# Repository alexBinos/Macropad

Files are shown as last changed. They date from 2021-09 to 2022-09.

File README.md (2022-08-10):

# Macropad

A 20 key macro-keyboard with extra hardware features including;

- 1x rotary encoder
- I2C breakout to support an OLED display
- Per-key RGB LED lighting and underglow lighting
- Hot-swap key switch sockets
- 4 port USB 2.0 HUB with 3 spare downstream ports

<br>

Power for the board and downstream USB ports is sourced from the upstream USB port. The board consumes 62mA with all LEDs powered off giving 438mA to be shared among the remaining 3 USB ports. With all LEDs powered up to pixel value 128 (recommended maximum) the board consumes 264mA.

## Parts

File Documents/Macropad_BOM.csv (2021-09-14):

Id | Designator | Package | Quantity | Designation | Description
1 | SW22 | SW_SPST_B3U-1000P | 1 | SW_Push | DFU reset switch
2 | D54;D53;D52;D51;D50;D49;D48;D47;D46;D45;D44;D43;D42;D41;D40;D39;D38;D37;D36;D35;D34;D33;D32;D31;D30;D28;D27;D26;D25;D24; | SK6812-MINI-E | 30 |  | RGB LEDs
3 | TP2;TP3;TP1 | TestPoint_Pad_D1.0mm | 3 | TestPoint | Test points (DNP)
4 | C30;C39;C46;C45;C37;C44;C2;C36;C33 | C_0603_1608Metric | 9 | 1uF | 0603 capacitor
5 | C16;C20;C14;C23;C38;C43;C42;C41;C40;C3;C35;C34;C32;C31;C29;C28;C27;C26;C25;C24;C22;C21;C19;C18;C17;C15;C13;C12;C11;C10;C9;C8;C7;C6;C5;C4 | C_0603_1608Metric | 36 | 100nF | 0603 capacitor
6 | U8;U6;U2 | SOT-23-6 | 3 | SRV05-4 | ESD diode array
7 | J5;J6;J4;J1 | USB_C_Receptacle_GCT_USB4085 | 4 | USB_C_Receptacle_USB2.0 | USB C connector
8 | FB3;FB2;FB1 | L_0805_2012Metric | 3 | Ferrite_Bead | Ferrite bead
9 | SW12;SW7;SW17;SW2;SW16;SW18;SW8;SW11;SW6;SW13;SW3;SW1;SW20;SW19;SW15;SW14;SW10;SW9;SW5;SW4; | CherryMX_1.00u_PCB_KailhSocket | 20 |  | Hot swap switch receptacle
10 | J3 | PinHeader_2x03_P2.54mm_Vertical_SMD | 1 | Conn_02x03_Odd_Even | ISP header
11 | U4 | TUSB2046b | 1 | TUSB2046b | USB hub controller
12 | R1;R13;R11;R10;R9;R21;R20;R19;R18;R14 | R_0603_1608Metric | 10 | 4K7 | 0603 resistor
13 | U5 | TQFP-44_10x10mm_P0.8mm | 1 | ATmega32U4-AU | uController
14 | X2 | 625L3C006M00000 | 1 | 625L3C006M00000 | 6MHz crystal (USB hub)
15 | R29;R28;R27;R26;R25;R24;R23;R22;R8;R7 | R_0603_1608Metric | 10 | 22R | 0603 resistor
16 | R6;R5 | R_0603_1608Metric | 2 | OPT | 0603 resistor
17 | R4;R3 | R_0603_1608Metric | 2 | 5K1 | 0603 resistor
18 | R2 | R_0603_1608Metric | 1 | 330R | 0603 resistor
19 | L1 | SMM2012E | 1 | L_Core_Iron_Coupled_1423 | Common mode choke
20 | D1 | D_0603_1608Metric | 1 | LED | Blue LED
21 | C1 | C_0603_1608Metric | 1 | 10uF | 0603 capacitor
22 | D22;D21;D20;D19;D18;D17;D16;D15;D14;D13;D12;D11;D10;D9;D8;D7;D6;D5;D4;D3;D2 | SOD323_HS | 21 | D | Diode
23 | X1 | KC2016K | 1 | KC2016K | 16MHz crystal (uController)
24 | U1 | TCR2EF33_SOT25 | 1 | TCR2EF33 | 3.3V 200mA LDO
25 | SW21 | RotaryEncoder_Alps_EC11E-Switch_Vertical_H20mm | 1 | Rotary_Encoder_Switch | Rotary encoder
26 | R16;R15 | R_0603_1608Metric | 2 | Rt | 0603 resistor
27 | J2 | PinSocket_1x04_P2.54mm_Vertical | 1 | Conn_01x04_Female | OLED display connector

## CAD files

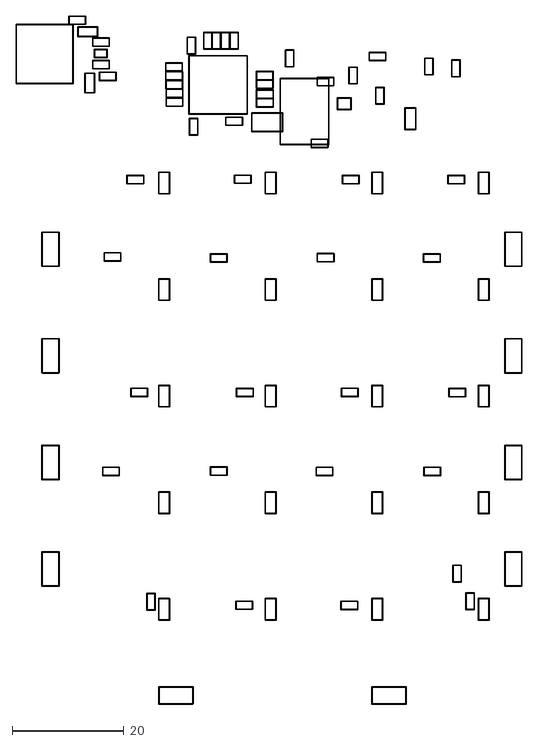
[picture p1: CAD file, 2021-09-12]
Mechanical/dxf/Macropad-B_CrtYd.dxf
90.4 x 123.0

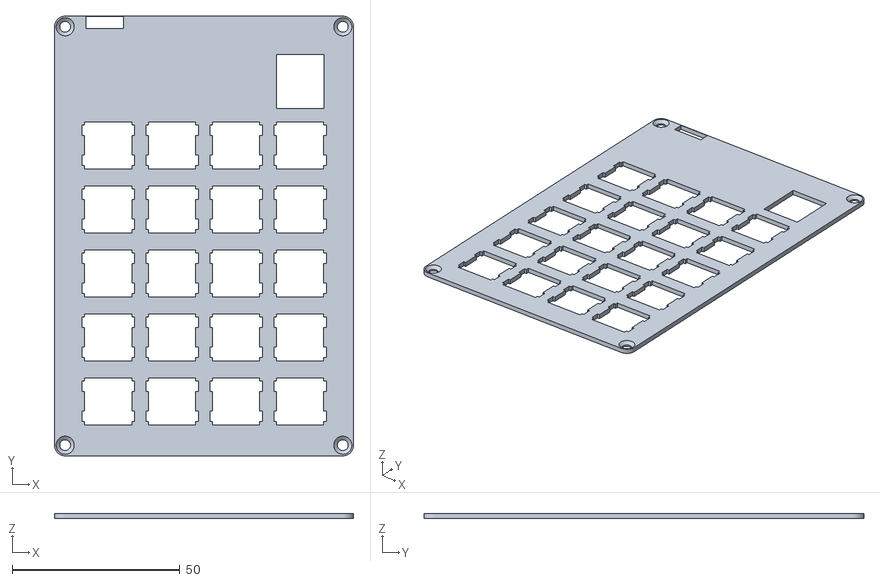
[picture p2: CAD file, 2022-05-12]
Mechanical/key_frame.STL
89.0 x 130.9 x 1.60

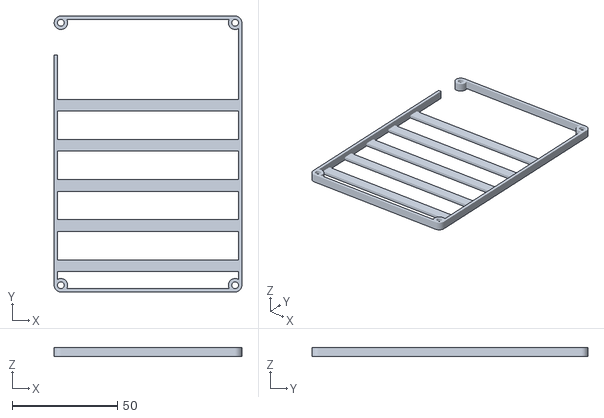
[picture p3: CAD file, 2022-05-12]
Mechanical/bottom_space_frame.STL
89.1 x 131.0 x 4.40

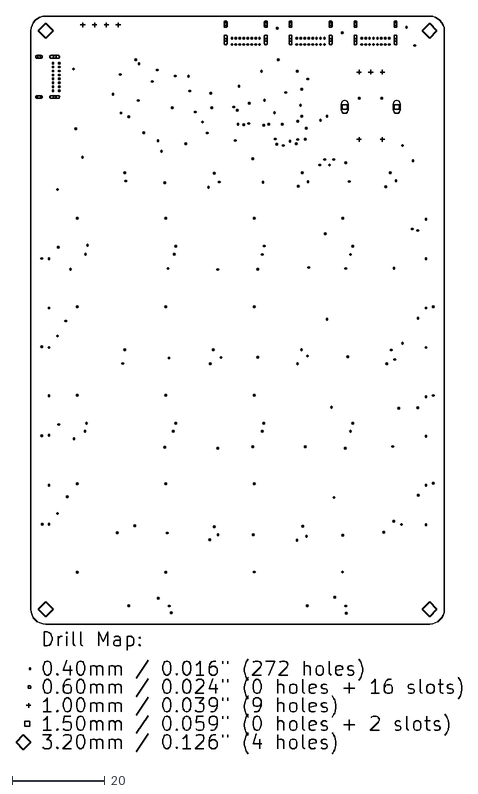
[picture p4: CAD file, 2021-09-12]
Mechanical/dxf/Macropad-PTH-drl_map.dxf
96.1 x 158.9

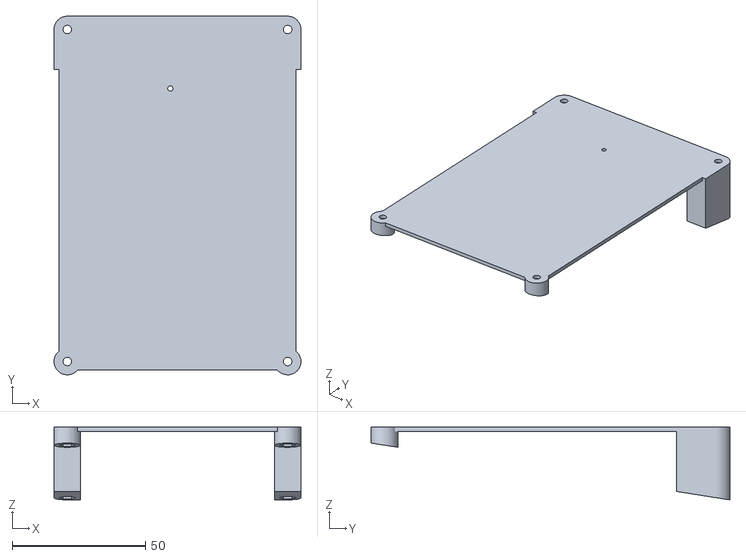
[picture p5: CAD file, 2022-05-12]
Mechanical/back_frame.STL
92.7 x 134.6 x 27.3

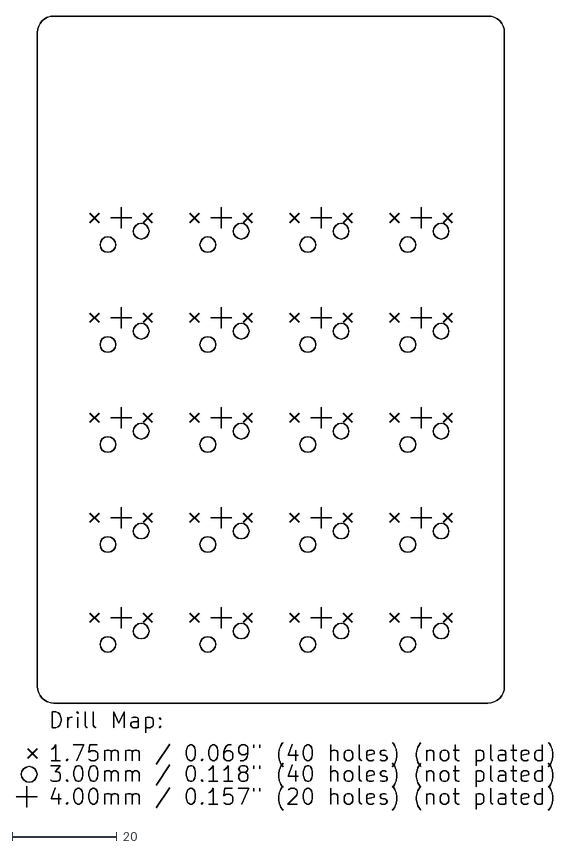
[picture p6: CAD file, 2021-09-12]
Mechanical/dxf/Macropad-NPTH-drl_map.dxf
102.3 x 151.3

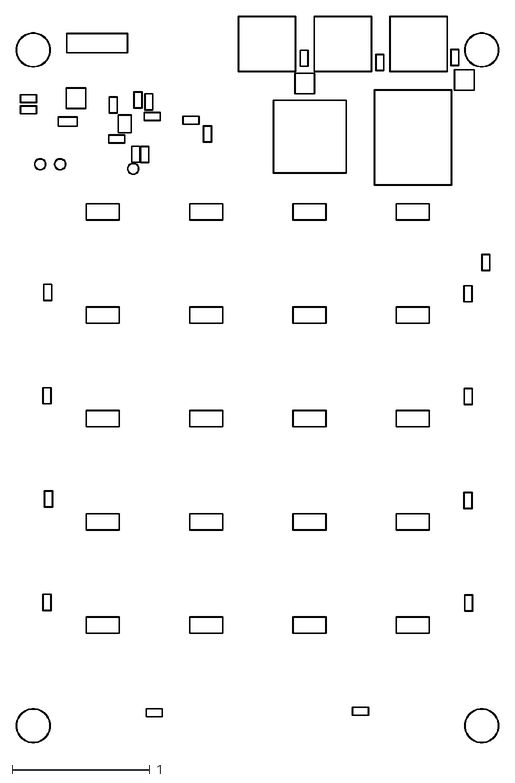
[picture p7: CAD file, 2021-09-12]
Mechanical/dxf/Macropad-F_CrtYd.dxf
3.50 x 5.27

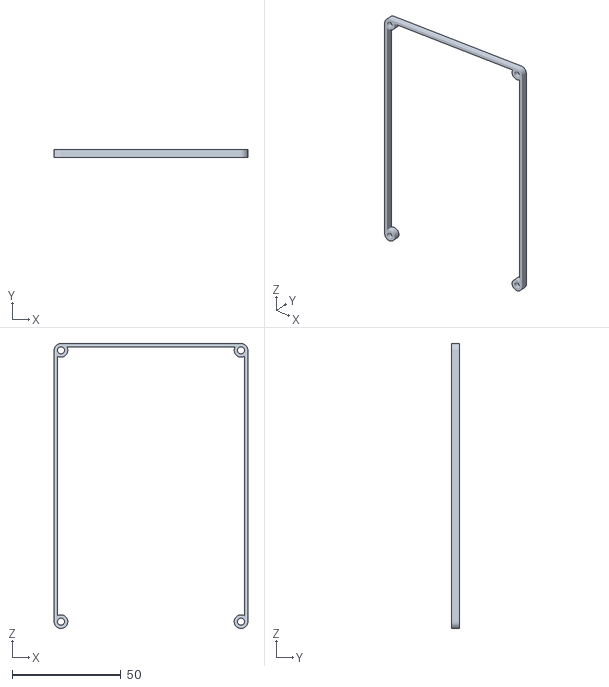
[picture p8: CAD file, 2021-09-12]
Mechanical/top_space_frame.STL
89.0 x 3.80 x 130.9

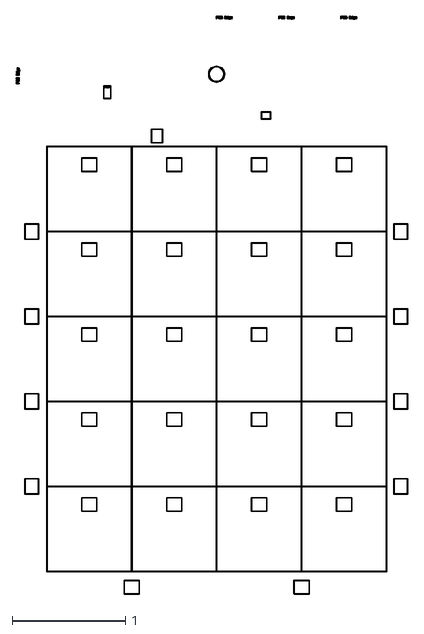
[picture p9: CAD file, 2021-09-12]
Mechanical/dxf/Macropad-Dwgs_User.dxf
3.45 x 5.10

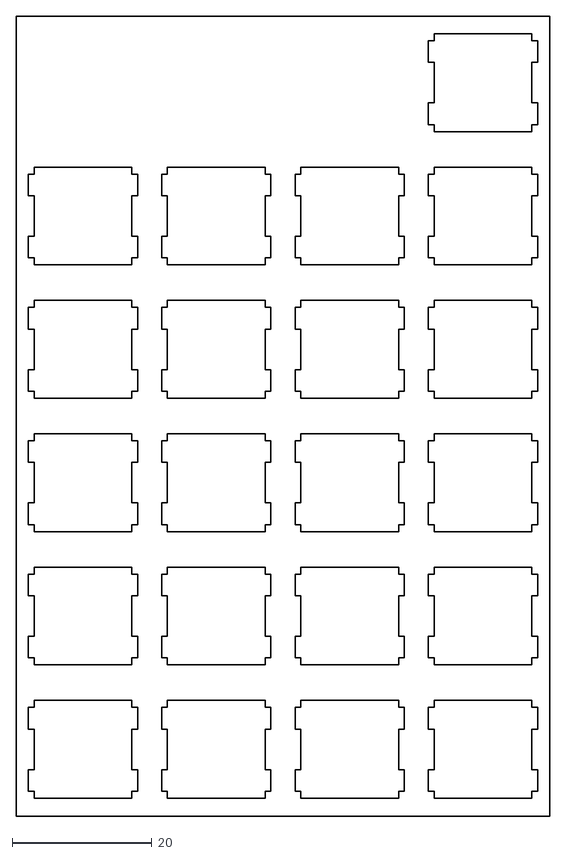
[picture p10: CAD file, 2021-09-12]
Mechanical/dxf/mx_key_frame_swillkb.dxf
76.2 x 114.3

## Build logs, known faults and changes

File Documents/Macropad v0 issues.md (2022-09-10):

## Macropad v0 issues

<br>

1. I2C lines connected incorrectly to ATMEGA32U4

The I2C lines are not connected to the dedicated I2C hardware pins PD1 and PD0 on the ATMEGA32U4. The OLED display cannot be driven on the v0 board.

*Fixes:* Cannot be fixed in hardware as the dedicated I2C pins are used to drive the switch matrix.

2. USB configuration resistors not connected correctly

Pull up/down resistors are required to be placed on the USB data lines to set the port directions on startup. Some USB HUB chips include these resistors in the package to simplify hardware design however the TUSB2046 does not include these and they need to be placed externally. AN-5052 provides a guide on how to correctly configure the USB data lines for host/peripheral configurations.

*Fixes:* 
<br>
To use the USB HUB, the 1K5 resistor can be soldered between R1 and R8. The 15K pull down resistors can be soldered between USB data lines and ground at the downstream connectors.
<br>
 
<p align="center" width="100%">
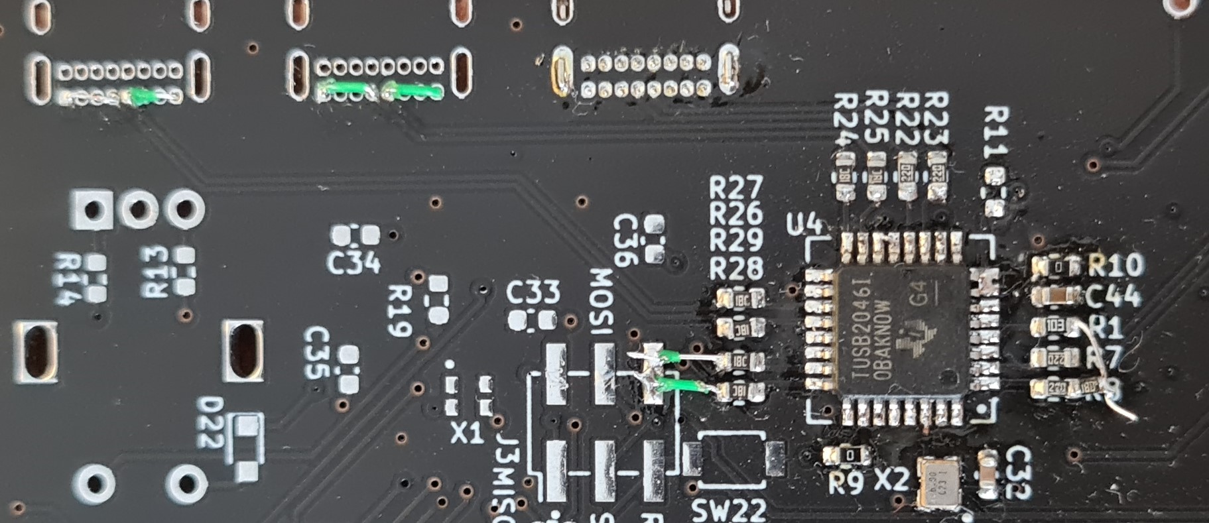
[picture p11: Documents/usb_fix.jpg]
     
</p>

<br>
If the USB HUB is not required, the TUSB2046 can not be placed and the USB data lines can be connected directly to the ATMEGA32U4 by joining pins 1 and 24, and pins 2 and 23 on the TUSB2046 footprint with wire.
<br>

<p align="center" width="100%">
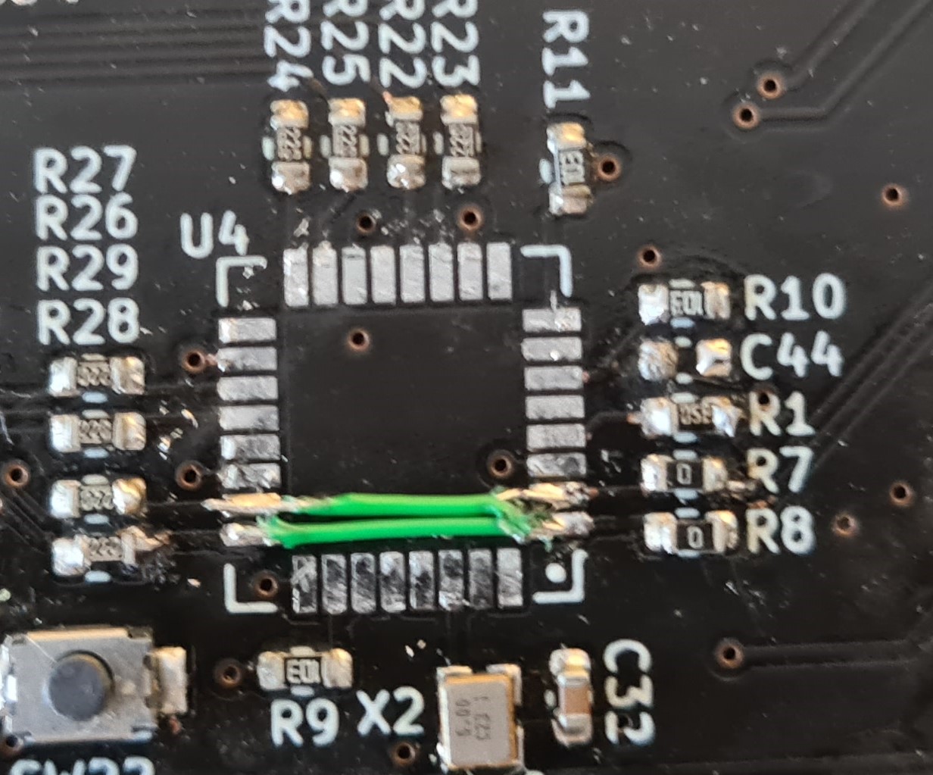
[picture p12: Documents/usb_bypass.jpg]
     
</p>

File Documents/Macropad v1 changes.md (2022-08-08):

## Macropad v1 changes

<br>

   1. Moved I2C lines to PD1/SDA and PD0/SCL
   2. Added 15K USB pull downs on USB HUB peripheral side
   3. Added 1K5 pull up on D+ on USB HUB host side
   4. Removed USB CMC bypass optionals
   5. Removed USB HUB configuration strap resistors
   6. Changed USB HUB BUSPWR mode to self powered (pulled down)
   7. Added optional pads to bypass the USB HUB
   8. Updated SK6812 footprint for better fitment
   9. Updated board name silk
   10. Moved underglow LED decoupling caps to avoid clashes with case
   11. Rounded corners on +3V3 plane

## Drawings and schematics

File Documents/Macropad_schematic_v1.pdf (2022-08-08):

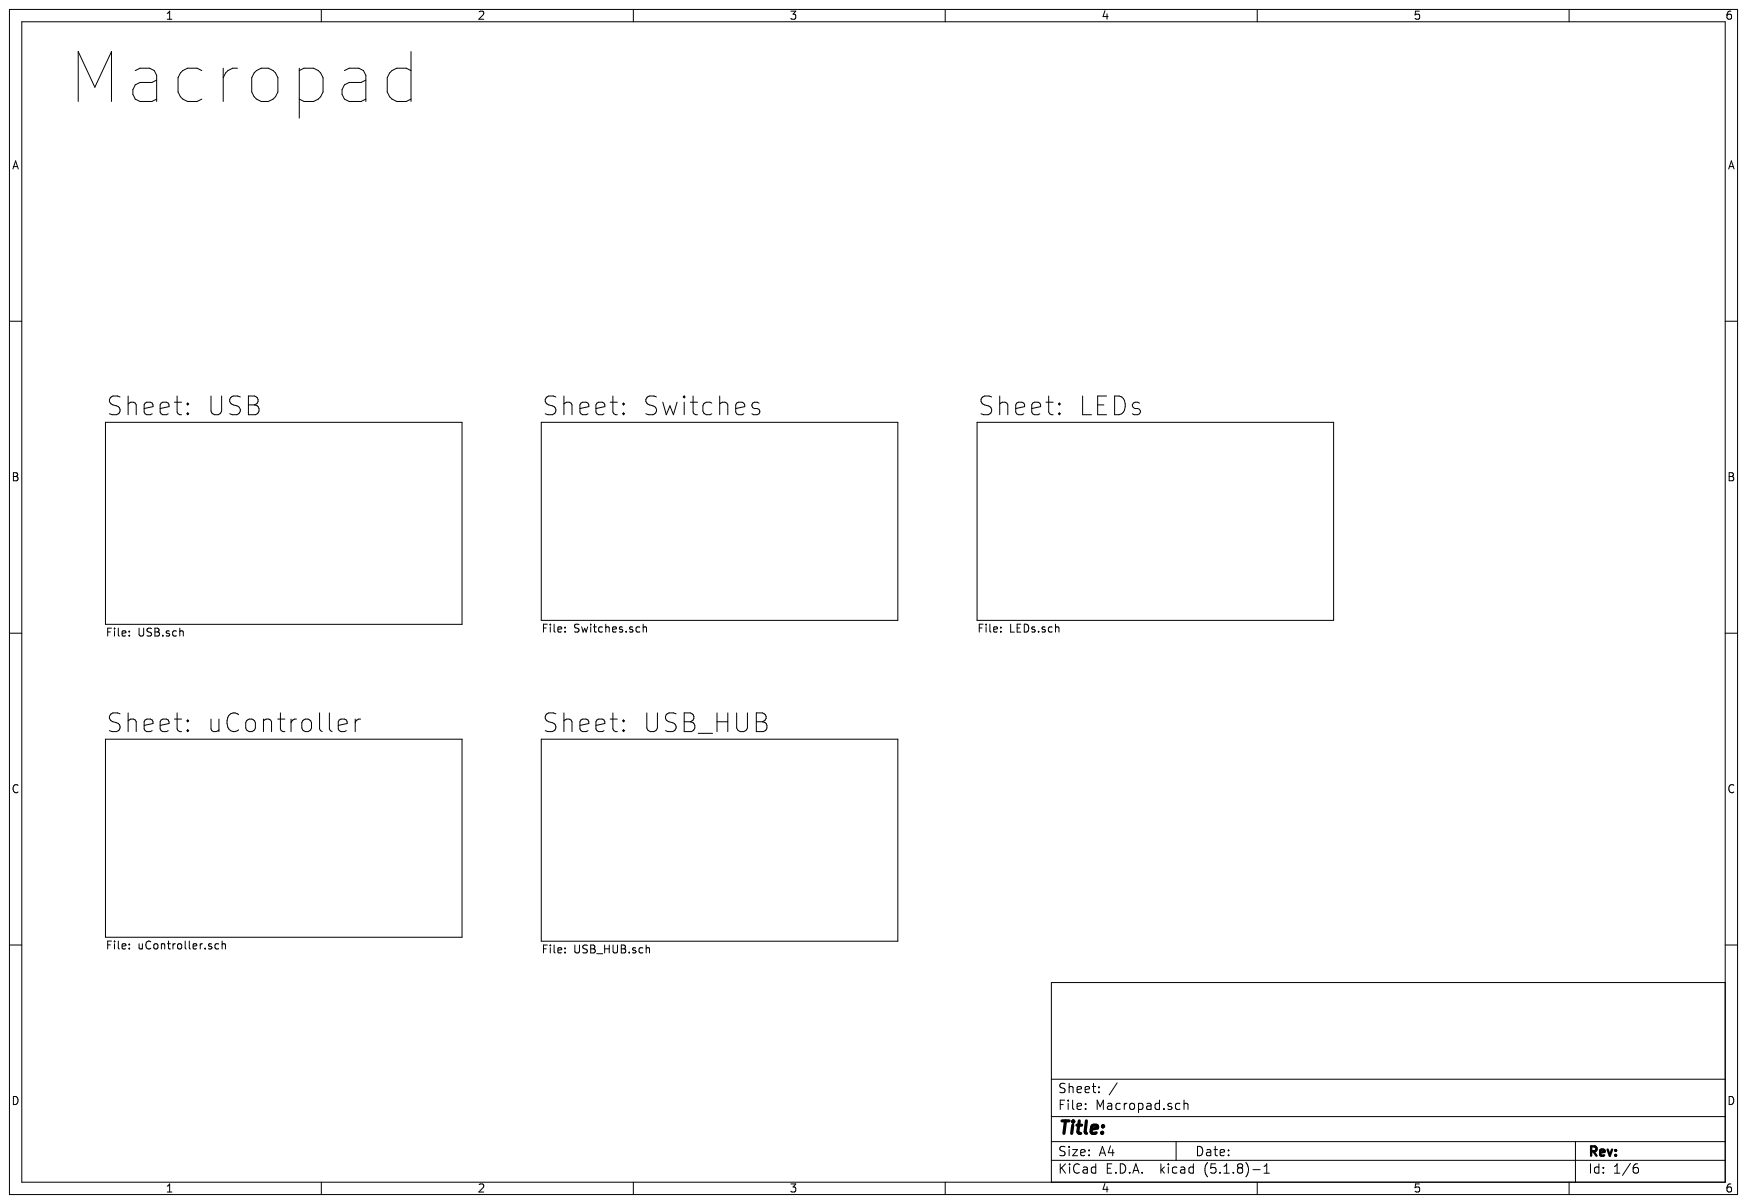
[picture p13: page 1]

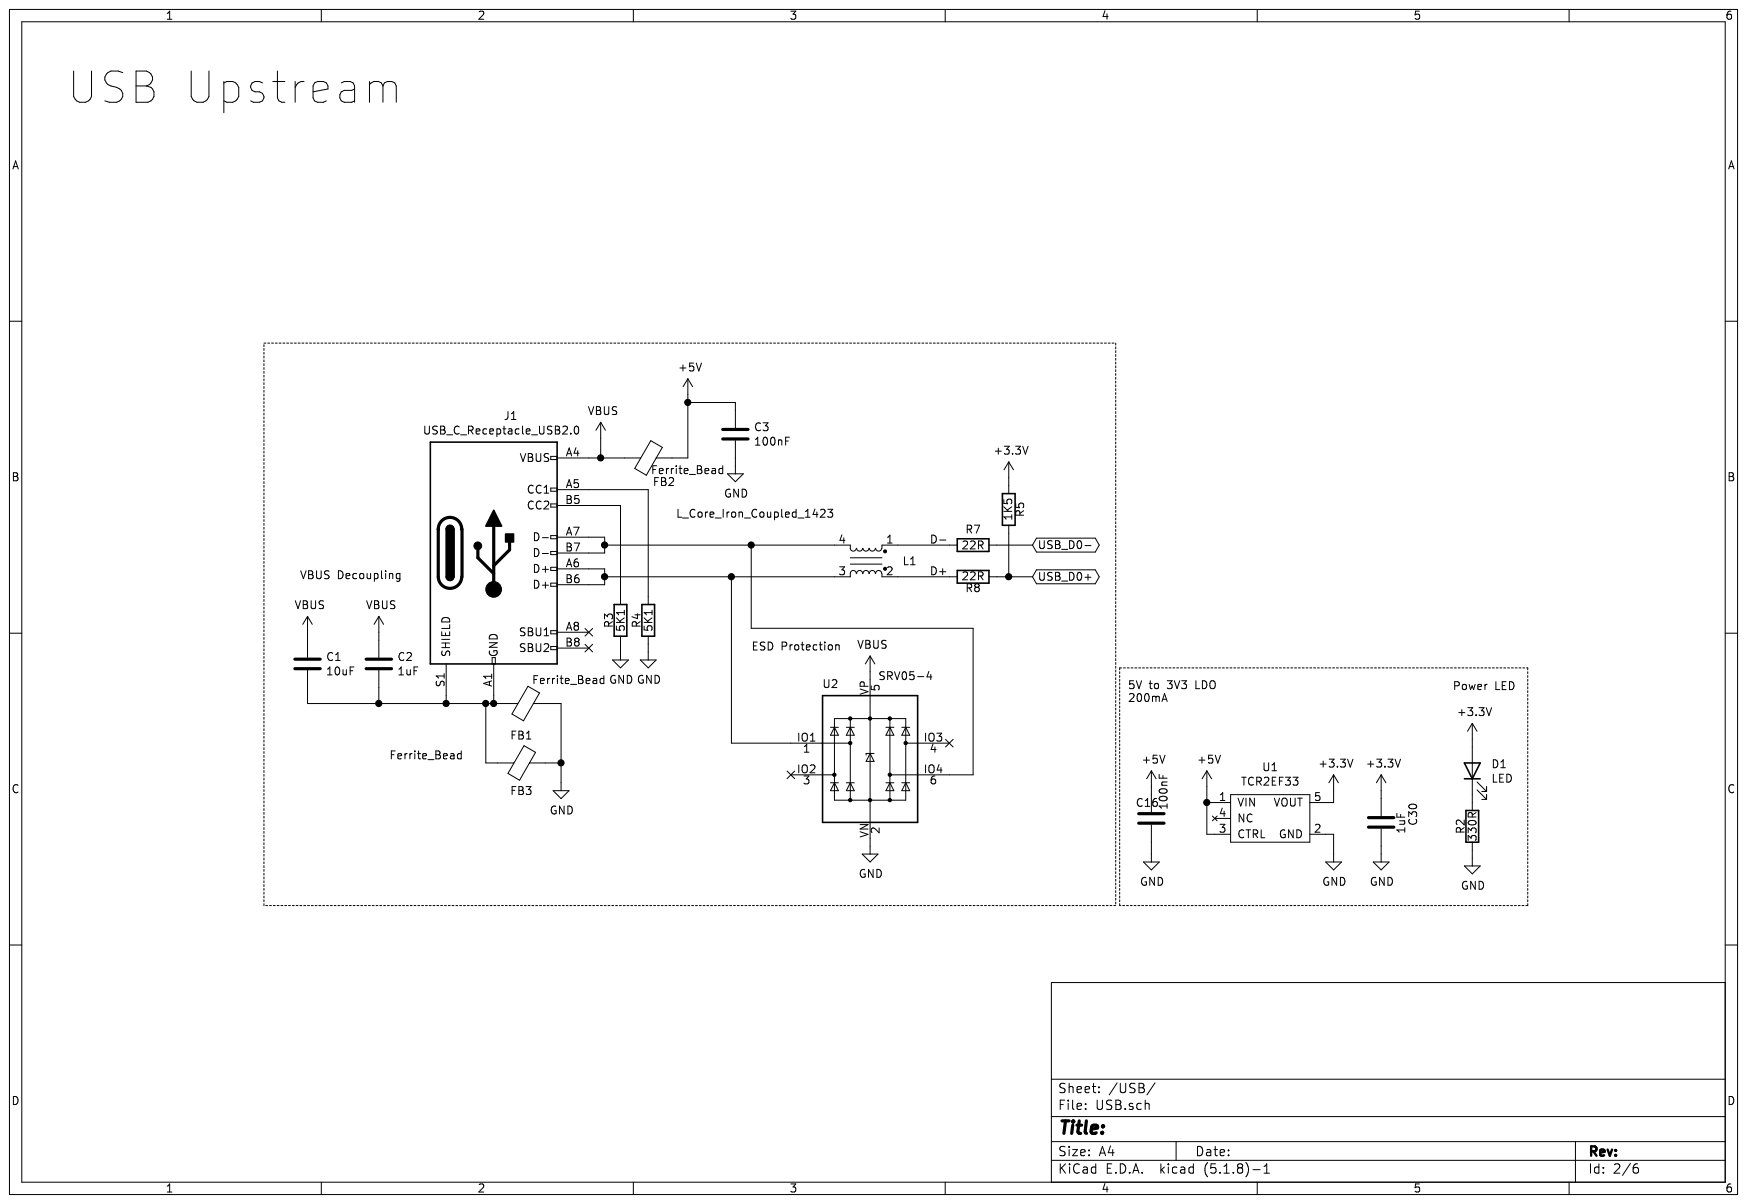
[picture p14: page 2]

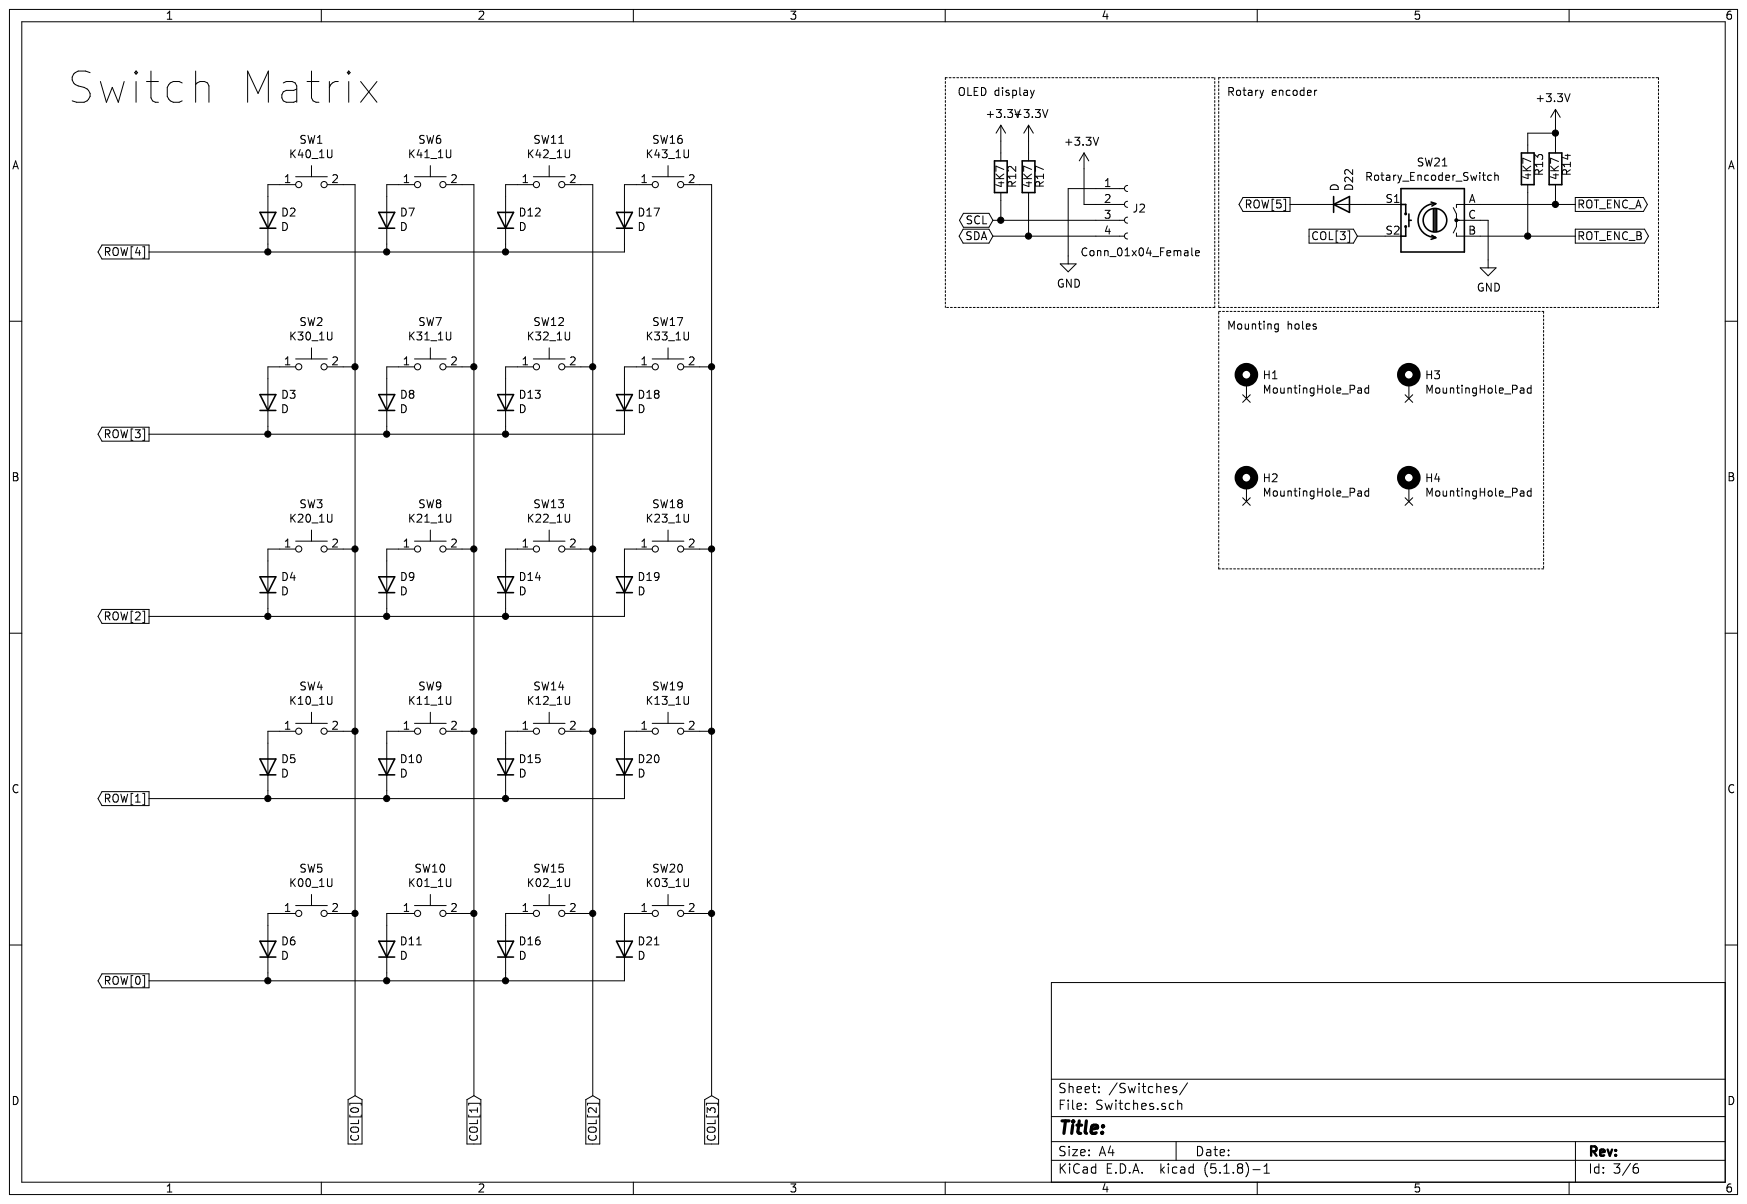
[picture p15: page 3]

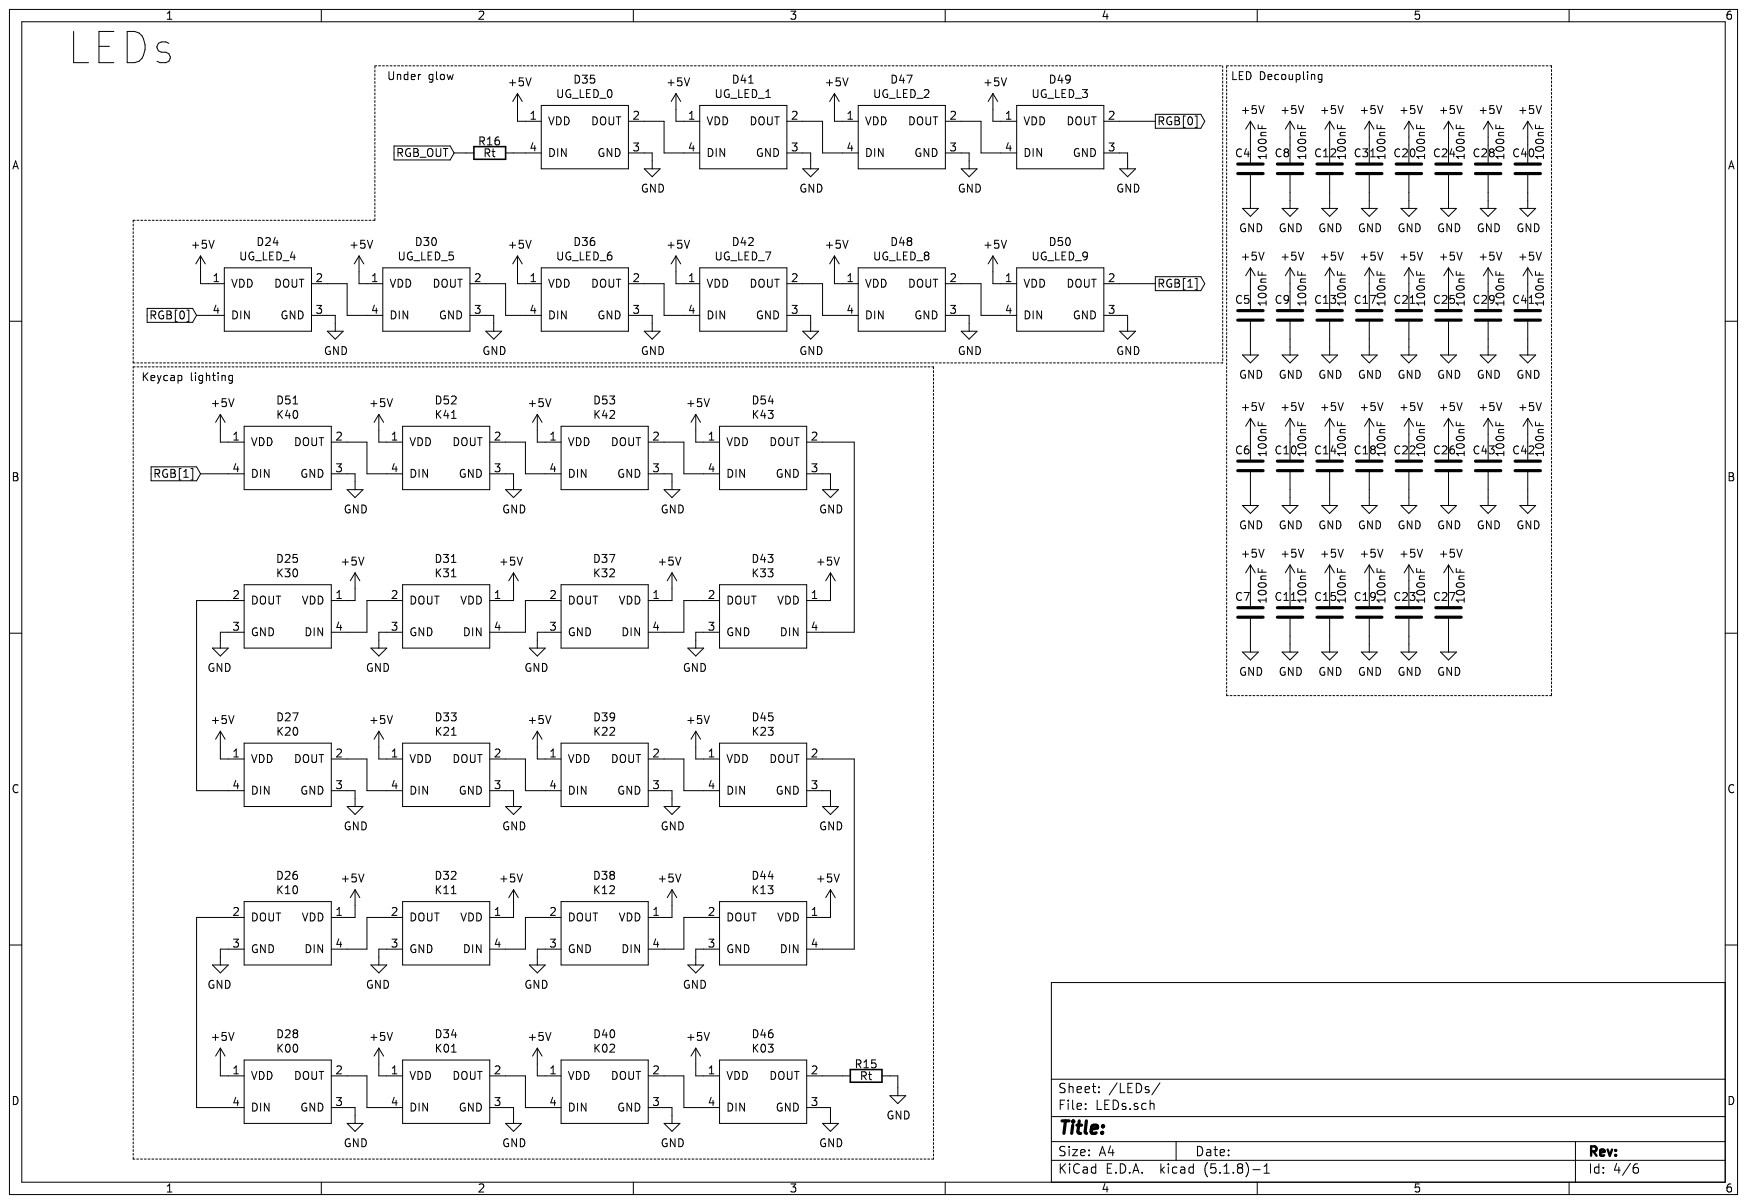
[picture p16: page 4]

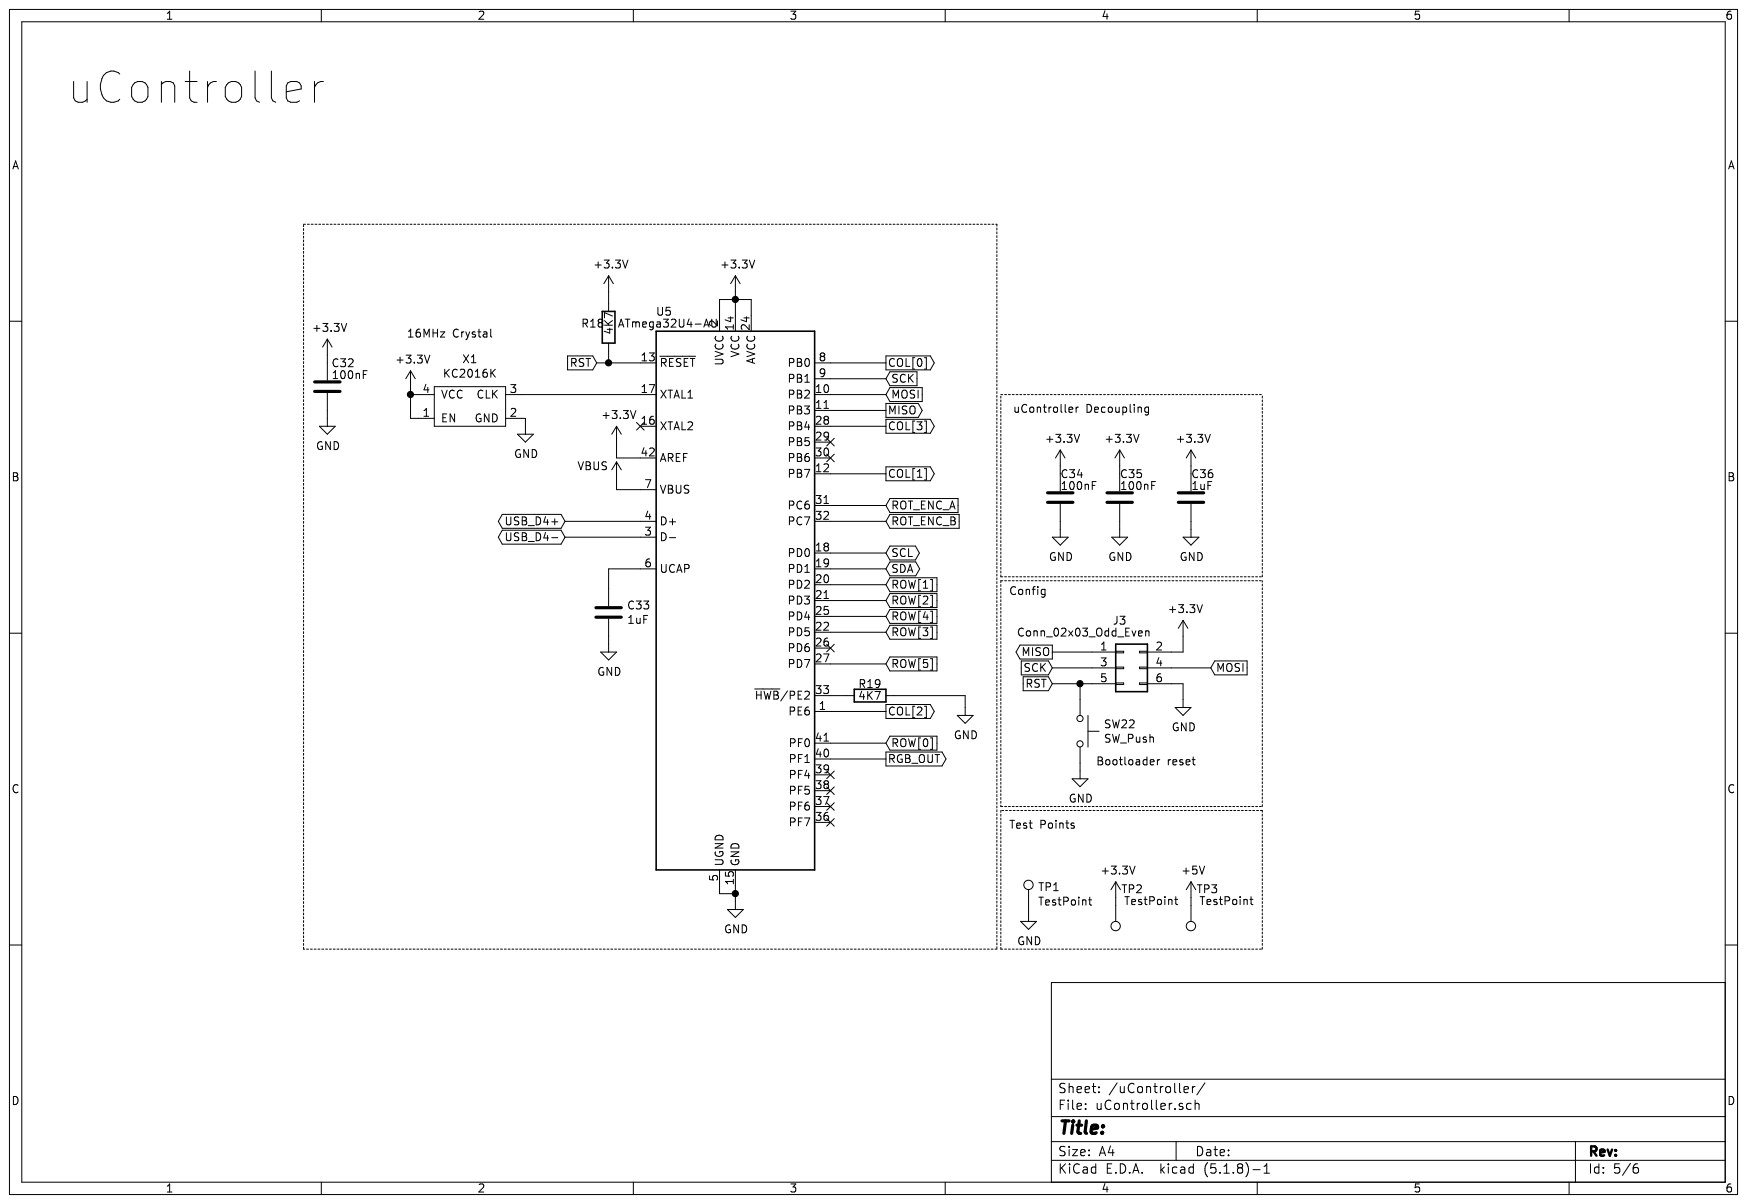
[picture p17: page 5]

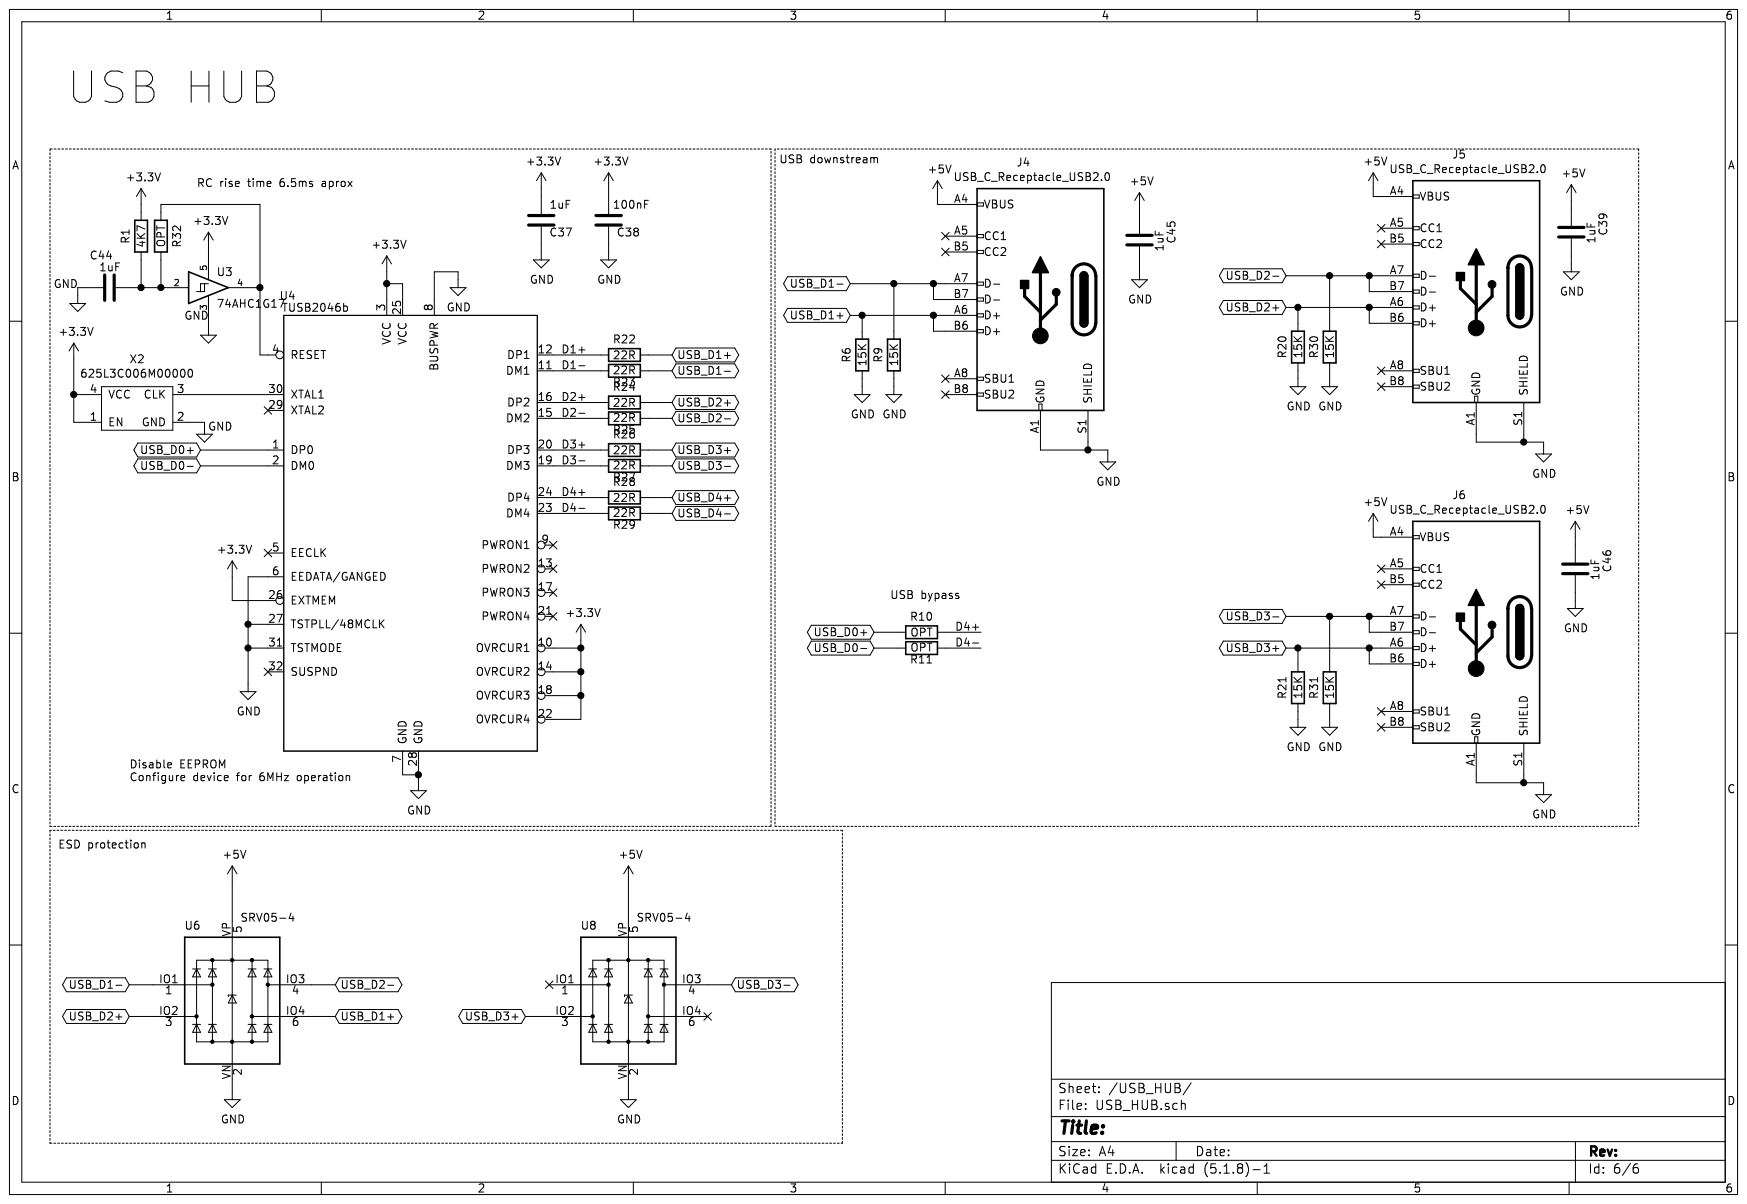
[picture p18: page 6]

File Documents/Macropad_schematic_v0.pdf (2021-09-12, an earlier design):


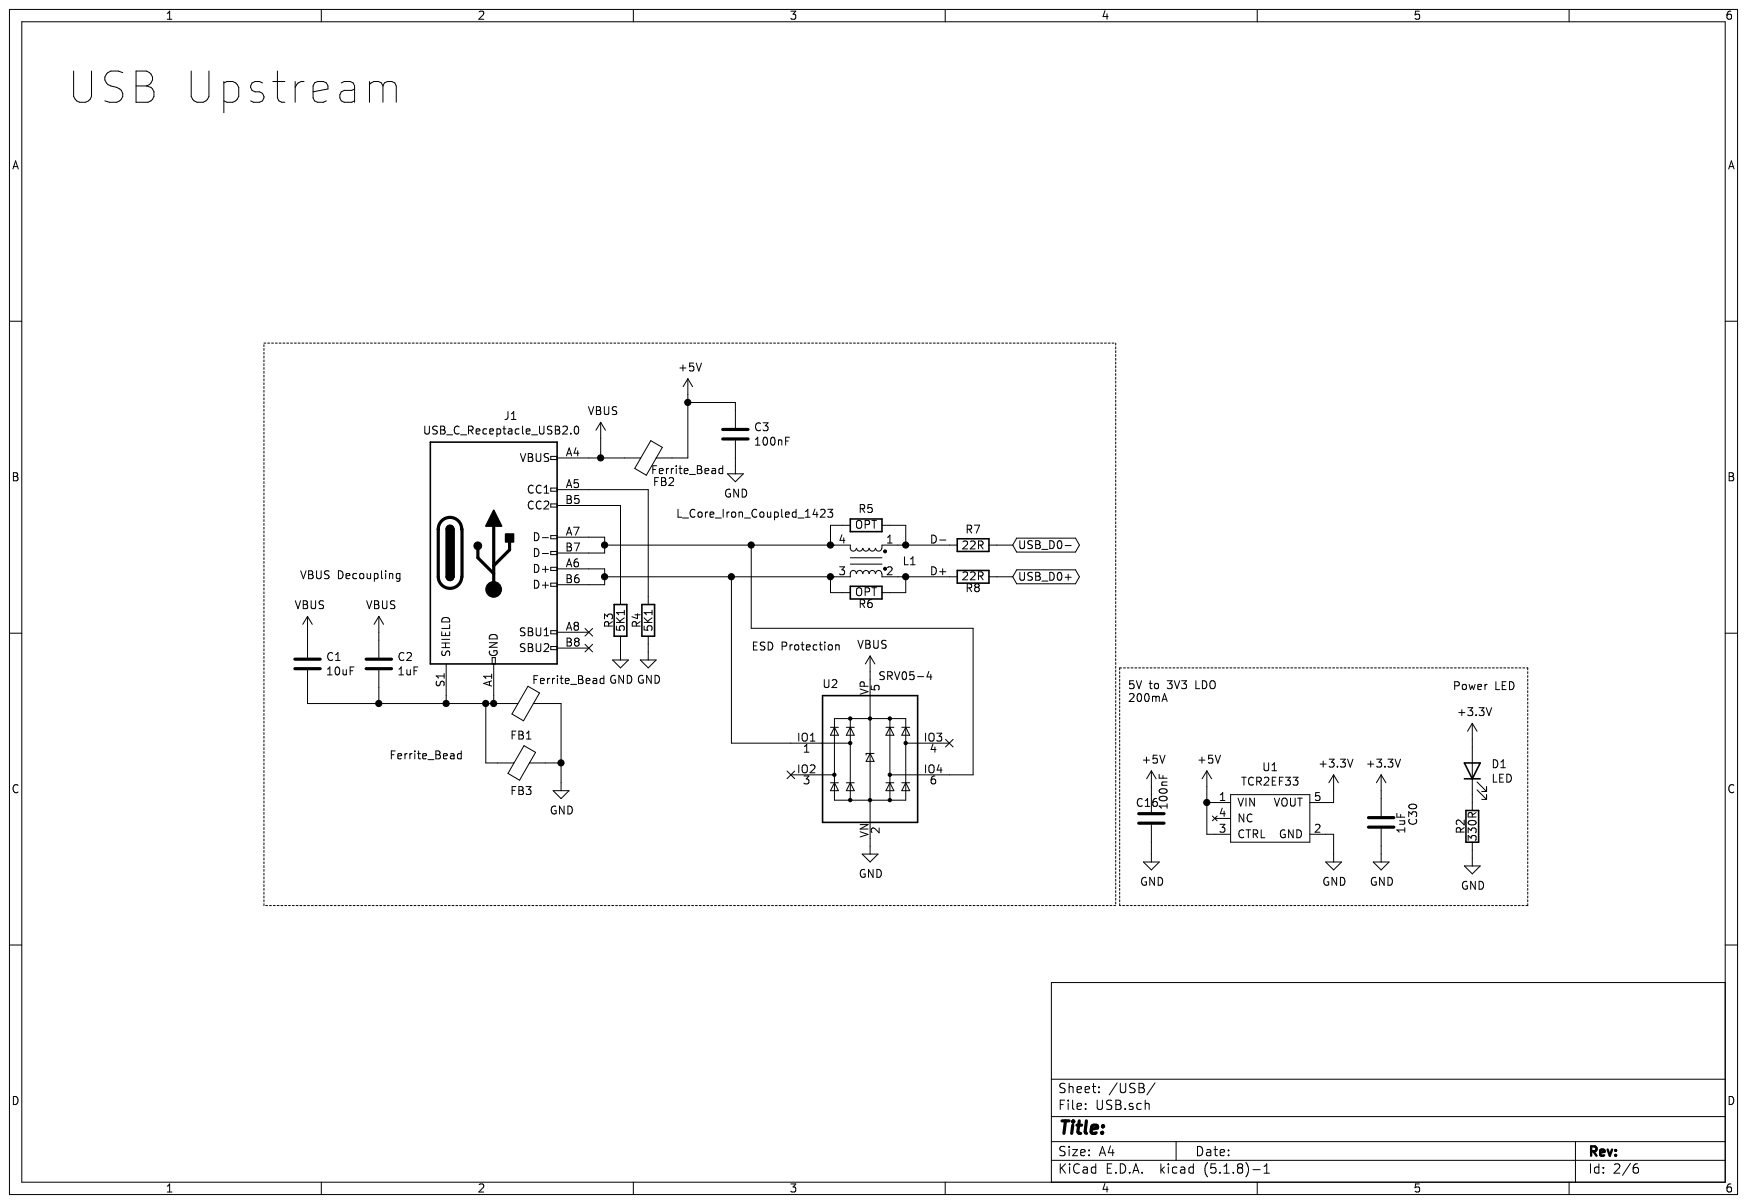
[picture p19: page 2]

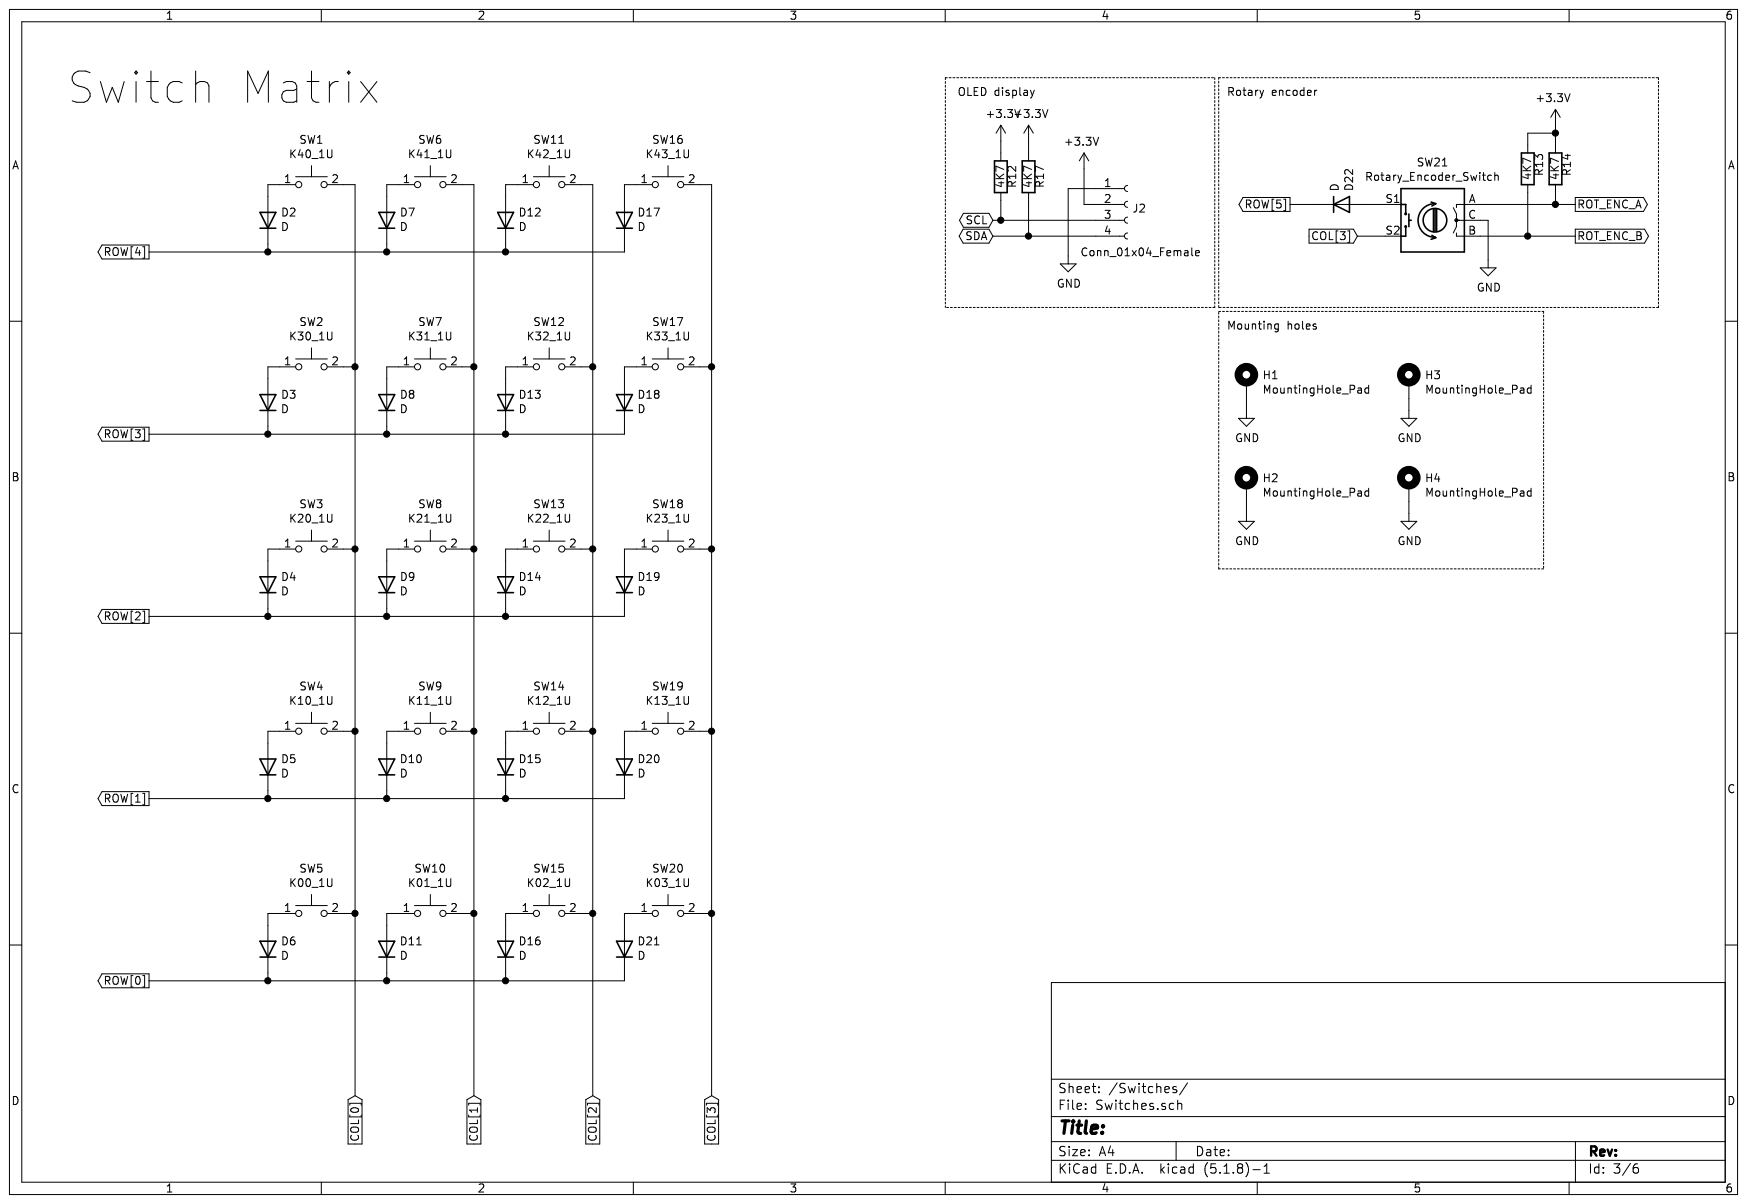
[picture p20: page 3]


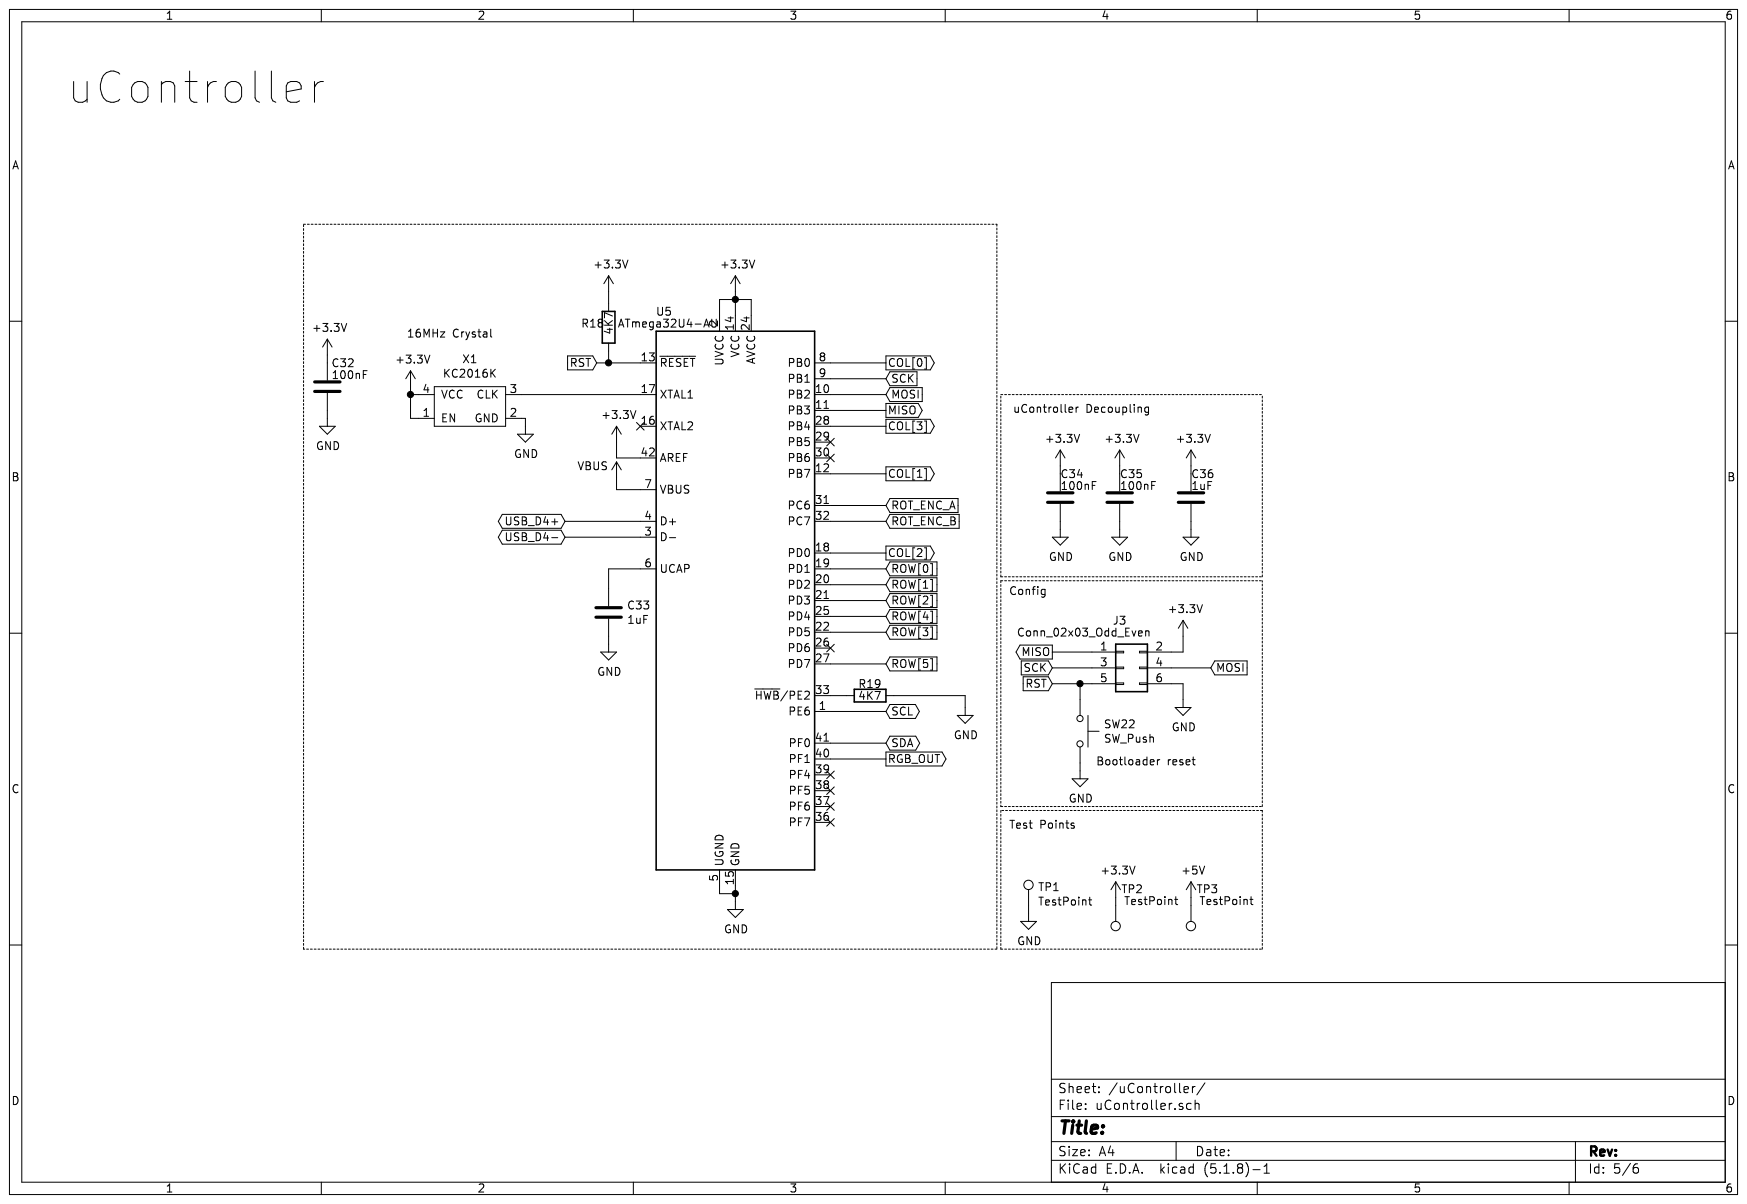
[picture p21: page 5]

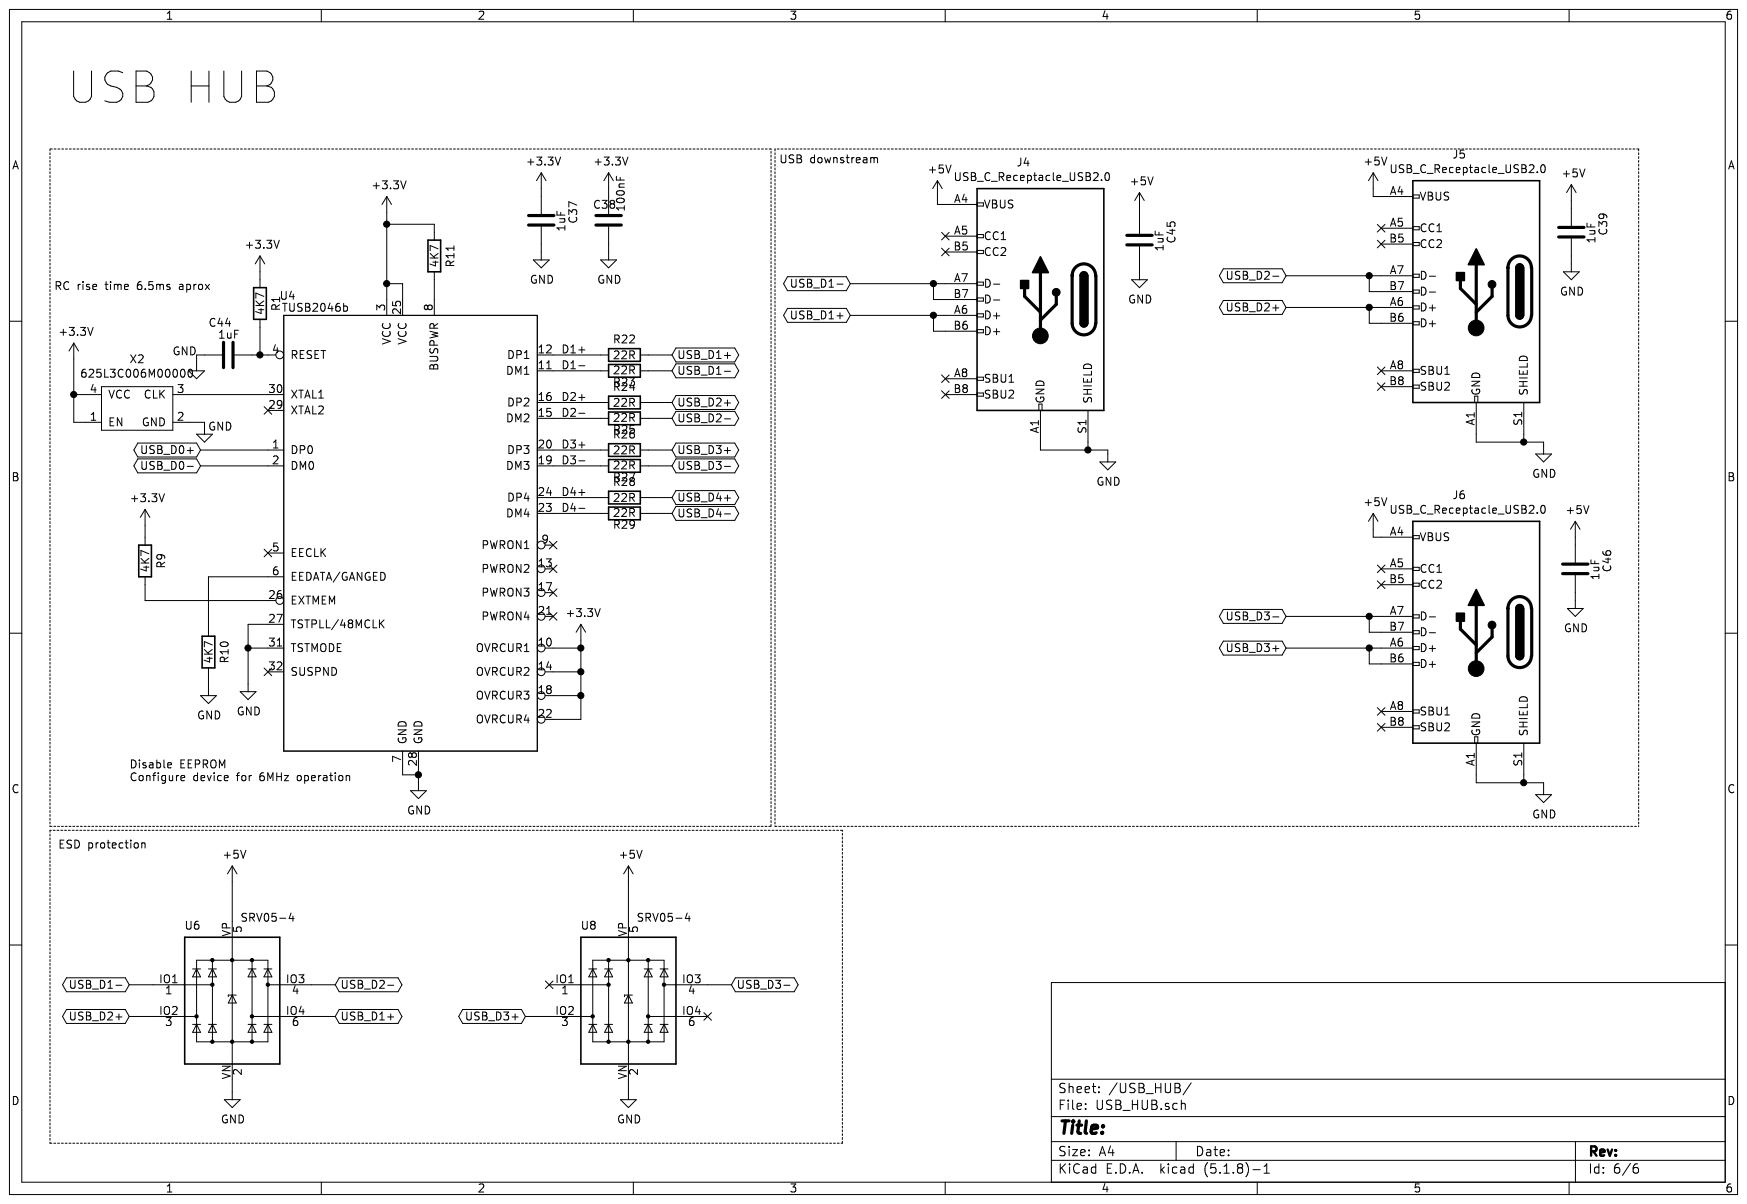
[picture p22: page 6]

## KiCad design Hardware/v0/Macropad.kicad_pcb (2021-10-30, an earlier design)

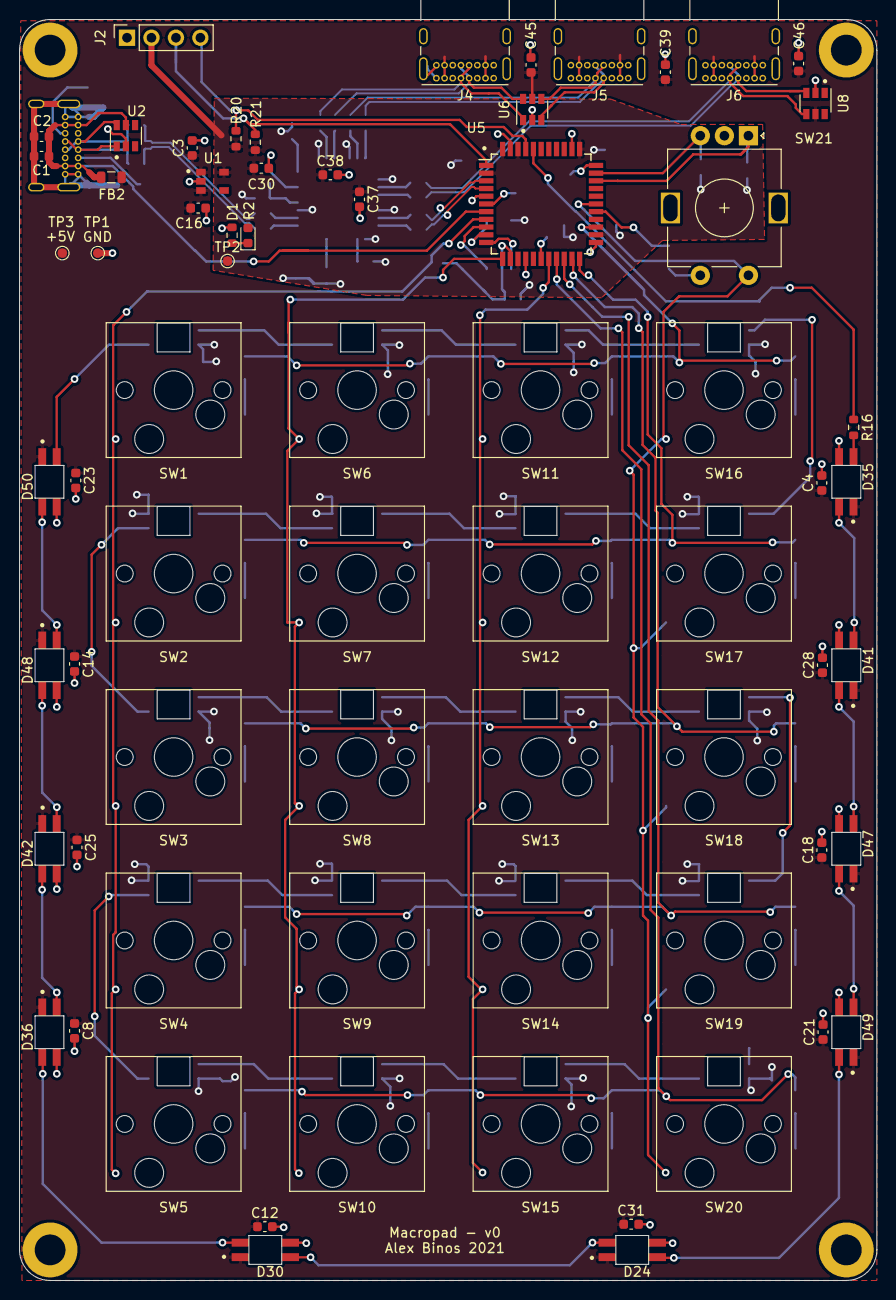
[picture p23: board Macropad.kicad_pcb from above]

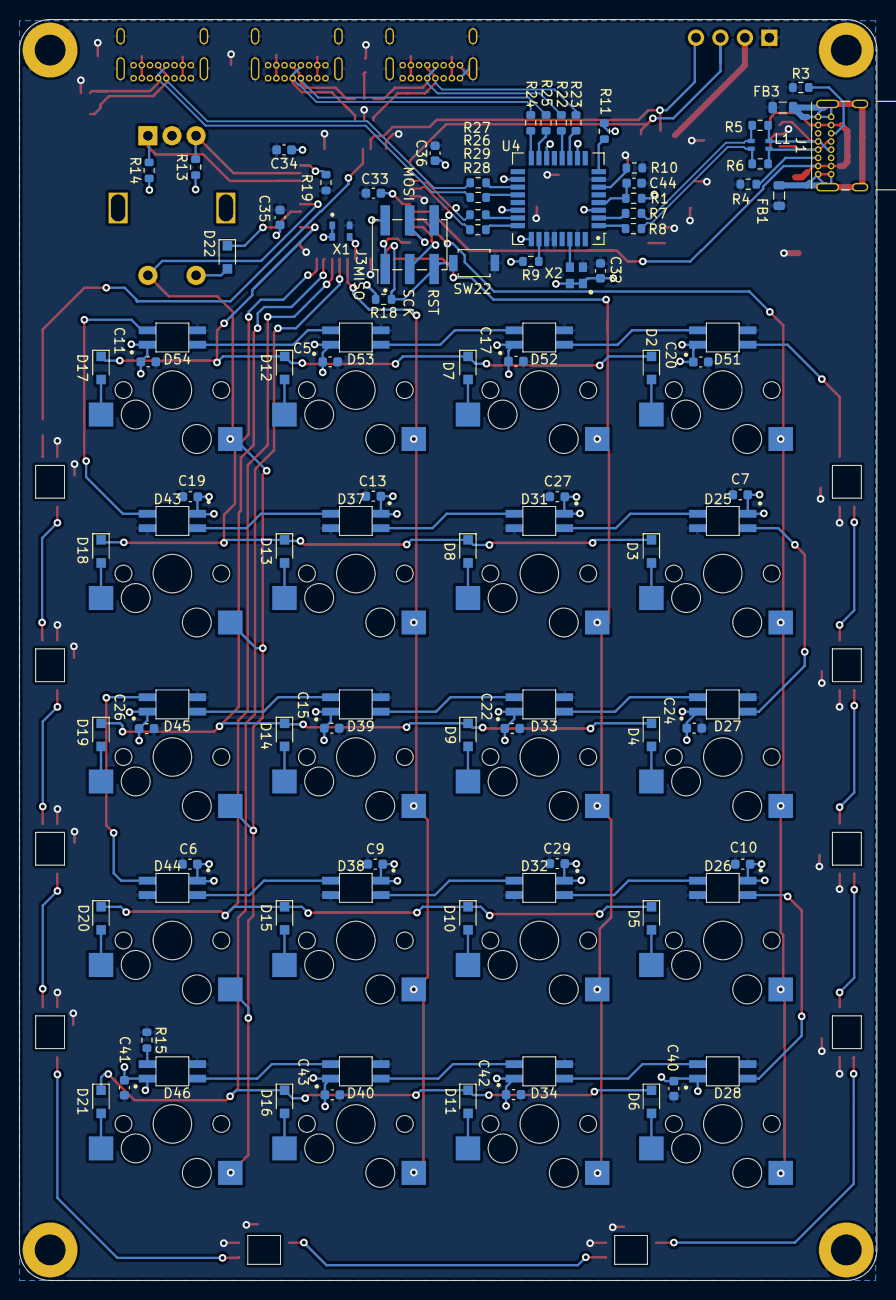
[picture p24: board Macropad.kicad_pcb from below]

Board: 2 copper layers, 89.0 x 130.9 mm, 172 parts (89 on the bottom side), 109 nets.

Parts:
C1: 10uF; C_0603_1608Metric
C2, C30, C33, C36, C37, C39, C44, C45, C46: 1uF; C_0603_1608Metric
C3, C4, C5, C6, C7, C8, C9, C10, C11, C12, C13, C14, C15, C16, C17, C18, C19, C20, C21, C22, C23, C24, C25, C26, C27, C28, C29, C31, C32, C34, C35, C38, C40, C41, C42, C43: 100nF; C_0603_1608Metric
D1: LED; D_0603_1608Metric
D2, D3, D4, D5, D6, D7, D8, D9, D10, D11, D12, D13, D14, D15, D16, D17, D18, D19, D20, D21, D22: D; SOD323_HS
D24: UG_LED_4; SK6812-MINI-E
D25: K30; SK6812-MINI-E
D26: K10; SK6812-MINI-E
D27: K20; SK6812-MINI-E
D28: K00; SK6812-MINI-E
D30: UG_LED_5; SK6812-MINI-E
D31: K31; SK6812-MINI-E
D32: K11; SK6812-MINI-E
D33: K21; SK6812-MINI-E
D34: K01; SK6812-MINI-E
D35: UG_LED_0; SK6812-MINI-E
D36: UG_LED_6; SK6812-MINI-E
D37: K32; SK6812-MINI-E
D38: K12; SK6812-MINI-E
D39: K22; SK6812-MINI-E
D40: K02; SK6812-MINI-E
D41: UG_LED_1; SK6812-MINI-E
D42: UG_LED_7; SK6812-MINI-E
D43: K33; SK6812-MINI-E
D44: K13; SK6812-MINI-E
D45: K23; SK6812-MINI-E
D46: K03; SK6812-MINI-E
D47: UG_LED_2; SK6812-MINI-E
D48: UG_LED_8; SK6812-MINI-E
D49: UG_LED_3; SK6812-MINI-E
D50: UG_LED_9; SK6812-MINI-E
D51: K40; SK6812-MINI-E
D52: K41; SK6812-MINI-E
D53: K42; SK6812-MINI-E
D54: K43; SK6812-MINI-E
FB1, FB2, FB3: Ferrite_Bead; L_0805_2012Metric
H1, H2, H3, H4: MountingHole_Pad; MountingHole_3.2mm_M3_ISO7380_Pad
J1, J4, J5, J6: USB_C_Receptacle_USB2.0; USB_C_Receptacle_GCT_USB4085
J2: Conn_01x04_Female; PinSocket_1x04_P2.54mm_Vertical
J3: Conn_02x03_Odd_Even; PinHeader_2x03_P2.54mm_Vertical_SMD
L1: L_Core_Iron_Coupled_1423; SMM2012E
R1, R9, R10, R11, R13, R14, R18, R19, R20, R21: 4K7; R_0603_1608Metric
R2: 330R; R_0603_1608Metric
R3, R4: 5K1; R_0603_1608Metric
R5, R6: OPT; R_0603_1608Metric
R7, R8, R22, R23, R24, R25, R26, R27, R28, R29: 22R; R_0603_1608Metric
R15, R16: Rt; R_0603_1608Metric
SW1: K40_1U; CherryMX_1.00u_PCB_KailhSocket
SW2: K30_1U; CherryMX_1.00u_PCB_KailhSocket
SW3: K20_1U; CherryMX_1.00u_PCB_KailhSocket
SW4: K10_1U; CherryMX_1.00u_PCB_KailhSocket
SW5: K00_1U; CherryMX_1.00u_PCB_KailhSocket
SW6: K41_1U; CherryMX_1.00u_PCB_KailhSocket
SW7: K31_1U; CherryMX_1.00u_PCB_KailhSocket
SW8: K21_1U; CherryMX_1.00u_PCB_KailhSocket
SW9: K11_1U; CherryMX_1.00u_PCB_KailhSocket
SW10: K01_1U; CherryMX_1.00u_PCB_KailhSocket
SW11: K42_1U; CherryMX_1.00u_PCB_KailhSocket
SW12: K32_1U; CherryMX_1.00u_PCB_KailhSocket
SW13: K22_1U; CherryMX_1.00u_PCB_KailhSocket
SW14: K12_1U; CherryMX_1.00u_PCB_KailhSocket
SW15: K02_1U; CherryMX_1.00u_PCB_KailhSocket
SW16: K43_1U; CherryMX_1.00u_PCB_KailhSocket
SW17: K33_1U; CherryMX_1.00u_PCB_KailhSocket
SW18: K23_1U; CherryMX_1.00u_PCB_KailhSocket
SW19: K13_1U; CherryMX_1.00u_PCB_KailhSocket
SW20: K03_1U; CherryMX_1.00u_PCB_KailhSocket
SW21: Rotary_Encoder_Switch; RotaryEncoder_Alps_EC11E-Switch_Vertical_H20mm
SW22: SW_Push; SW_SPST_B3U-1000P
TP1, TP2, TP3: TestPoint; TestPoint_Pad_D1.0mm
U1: TCR2EF33; TCR2EF33_SOT25
U2, U6, U8: SRV05-4; SOT-23-6
U4: TUSB2046b
U5: ATmega32U4-AU; TQFP-44_10x10mm_P0.8mm
X1: KC2016K
X2: 625L3C006M00000

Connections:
+3V3: C30.1, C32.1, C34.1, C35.1, C36.1, C37.1, C38.1, D1.2, J2.2, J3.2, R1.2, R9.2, R11.2, R13.1, R14.1, R18.1, R20.1, R21.1, TP2.1, U1.5, U4.3, U4.10, U4.14, U4.18, U4.22, U4.25, U5.2, U5.14, U5.24, U5.34, U5.42, U5.44, X1.1, X1.4, X2.1, X2.4
+5V: C3.1, C4.1, C5.1, C6.1, C7.1, C8.1, C9.1, C10.1, C11.1, C12.1, C13.1, C14.1, C15.1, C16.1, C17.1, C18.1, C19.1, C20.1, C21.1, C22.1, C23.1, C24.1, C25.1, C26.1, C27.1, C28.1, C29.1, C31.1, C39.1, C40.1, C41.1, C42.1, C43.1, C45.1, C46.1, D24.1, D25.1, D26.1, D27.1, D28.1, D30.1, D31.1, D32.1, D33.1, D34.1, D35.1, D36.1, D37.1, D38.1, D39.1, D40.1, D41.1, D42.1, D43.1, D44.1, D45.1, D46.1, D47.1, D48.1, D49.1, D50.1, D51.1, D52.1, D53.1, D54.1, FB2.1, J4.A4, J4.A9, J4.B4, J4.B9, J5.A4, J5.A9, J5.B4, J5.B9, J6.A4, J6.A9, J6.B4, J6.B9, TP3.1, U1.1, U1.3, U6.5, U8.5
/USB/D+: L1.2, R6.1, R8.2
/USB/D-: L1.1, R5.1, R7.2
/USB_HUB/D1+: R22.2, U4.12
/USB_HUB/D1-: R23.2, U4.11
/USB_HUB/D2+: R24.2, U4.16
/USB_HUB/D2-: R25.2, U4.15
/USB_HUB/D3+: R26.2, U4.20
/USB_HUB/D3-: R27.2, U4.19
/USB_HUB/D4+: R28.2, U4.24
/USB_HUB/D4-: R29.2, U4.23
COL[0]: SW1.2, SW2.2, SW3.2, SW4.2, SW5.2, U5.8
COL[1]: SW6.2, SW7.2, SW8.2, SW9.2, SW10.2, U5.12
COL[2]: SW11.2, SW12.2, SW13.2, SW14.2, SW15.2, U5.18
COL[3]: SW16.2, SW17.2, SW18.2, SW19.2, SW20.2, SW21.S2, U5.28
GND: C3.2, C4.2, C5.2, C6.2, C7.2, C8.2, C9.2, C10.2, C11.2, C12.2, C13.2, C14.2, C15.2, C16.2, C17.2, C18.2, C19.2, C20.2, C21.2, C22.2, C23.2, C24.2, C25.2, C26.2, C27.2, C28.2, C29.2, C30.2, C31.2, C32.2, C33.2, C34.2, C35.2, C36.2, C37.2, C38.2, C39.2, C40.2, C41.2, C42.2, C43.2, C44.1, C45.2, C46.2, D24.3, D25.3, D26.3, D27.3, D28.3, D30.3, D31.3, D32.3, D33.3, D34.3, D35.3, D36.3, D37.3, D38.3, D39.3, D40.3, D41.3, D42.3, D43.3, D44.3, D45.3, D46.3, D47.3, D48.3, D49.3, D50.3, D51.3, D52.3, D53.3, D54.3, FB1.1, FB3.1, H1.1, H2.1, H3.1, H4.1, J2.1, J3.6, J4.A1, J4.A12, J4.B1, J4.B12, J4.S1, J5.A1, J5.A12, J5.B1, J5.B12, J5.S1, J6.A1, J6.A12, J6.B1, J6.B12, J6.S1, R2.1, R3.1, R4.1, R10.1, R15.1, R19.2, SW21.C, SW22.2, TP1.1, U1.2, U2.2, U4.7, U4.27, U4.28, U4.31, U5.5, U5.15, U5.23, U5.35, U5.43, U6.2, U8.2, X1.2, X2.2
MISO: J3.1, U5.11
MOSI: J3.4, U5.10
unnamed: C1.2, C2.2, FB1.2, FB3.2, J1.A1, J1.A12, J1.B1, J1.B12, J1.S1
unnamed: C33.1, U5.6
unnamed: C44.2, R1.1, U4.4
unnamed: D1.1, R2.2
unnamed: D2.2, SW1.1
unnamed: D3.2, SW2.1
unnamed: D4.2, SW3.1
unnamed: D5.2, SW4.1
unnamed: D6.2, SW5.1
unnamed: D7.2, SW6.1
unnamed: D8.2, SW7.1
unnamed: D9.2, SW8.1
unnamed: D10.2, SW9.1
unnamed: D11.2, SW10.1
unnamed: D12.2, SW11.1
unnamed: D13.2, SW12.1
unnamed: D14.2, SW13.1
unnamed: D15.2, SW14.1
unnamed: D16.2, SW15.1
unnamed: D17.2, SW16.1
unnamed: D18.2, SW17.1
unnamed: D19.2, SW18.1
unnamed: D20.2, SW19.1
unnamed: D21.2, SW20.1
unnamed: D22.2, SW21.S1
unnamed: D24.2, D30.4
unnamed: D25.2, D27.4
unnamed: D25.4, D31.2
unnamed: D26.2, D28.4
unnamed: D26.4, D32.2
unnamed: D27.2, D33.4
unnamed: D28.2, D34.4
unnamed: D30.2, D36.4
unnamed: D31.4, D37.2
unnamed: D32.4, D38.2
unnamed: D33.2, D39.4
unnamed: D34.2, D40.4
unnamed: D35.2, D41.4
unnamed: D35.4, R16.2
unnamed: D36.2, D42.4
unnamed: D37.4, D43.2
unnamed: D38.4, D44.2
unnamed: D39.2, D45.4
unnamed: D40.2, D46.4
unnamed: D41.2, D47.4
unnamed: D42.2, D48.4
unnamed: D43.4, D54.2
unnamed: D44.4, D45.2
unnamed: D46.2, R15.2
unnamed: D47.2, D49.4
unnamed: D48.2, D50.4
unnamed: D51.2, D52.4
unnamed: D52.2, D53.4
unnamed: D53.2, D54.4
unnamed: J1.A5, R4.2
unnamed: J1.A6, J1.B6, L1.3, R6.2, U2.1
unnamed: J1.A7, J1.B7, L1.4, R5.2, U2.6
unnamed: J1.B5, R3.2
unnamed: R9.1, U4.26
unnamed: R10.2, U4.6
unnamed: R11.1, U4.8
unnamed: R19.1, U5.33
unnamed: U4.30, X2.3
unnamed: U5.17, X1.3
RGB[0]: D24.4, D49.2
RGB[1]: D50.2, D51.4
RGB_OUT: R16.1, U5.40
ROT_ENC_A: R14.2, SW21.A, U5.31
ROT_ENC_B: R13.2, SW21.B, U5.32
ROW[0]: D6.1, D11.1, D16.1, D21.1, U5.19
ROW[1]: D5.1, D10.1, D15.1, D20.1, U5.20
ROW[2]: D4.1, D9.1, D14.1, D19.1, U5.21
ROW[3]: D3.1, D8.1, D13.1, D18.1, U5.22
ROW[4]: D2.1, D7.1, D12.1, D17.1, U5.25
ROW[5]: D22.1, U5.27
RST: J3.5, R18.2, SW22.1, U5.13
SCK: J3.3, U5.9
SCL: J2.3, R21.2, U5.1
SDA: J2.4, R20.2, U5.41
USB_D0+: R8.1, U4.1
USB_D0-: R7.1, U4.2
USB_D1+: J4.A6, J4.B6, R22.1, U6.6
USB_D1-: J4.A7, J4.B7, R23.1, U6.1
USB_D2+: J5.A6, J5.B6, R24.1, U6.3
USB_D2-: J5.A7, J5.B7, R25.1, U6.4
USB_D3+: J6.A6, J6.B6, R26.1, U8.3
USB_D3-: J6.A7, J6.B7, R27.1, U8.4
USB_D4+: R28.1, U5.4
USB_D4-: R29.1, U5.3
VBUS: C1.1, C2.1, FB2.2, J1.A4, J1.A9, J1.B4, J1.B9, U2.5, U5.7

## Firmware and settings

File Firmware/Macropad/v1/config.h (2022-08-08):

#pragma once

#include "config_common.h"

/* USB Device descriptor parameter */
#define VENDOR_ID       0x1234
#define PRODUCT_ID      0x5678
#define DEVICE_VER      0x0000
#define MANUFACTURER    Alex Binos
#define PRODUCT         Macropad

/* Switch matrix dimensions */
#define MATRIX_ROWS 6
#define MATRIX_COLS 16

/* Micro controller pins */
#define MATRIX_ROW_PINS { F0, D2, D3, D5, D4, D7}
#define MATRIX_COL_PINS { B0, B7, E6, B4}
#define UNUSED_PINS { B5, B6, D6, E2, F4, F5, F6, F7 }

/* COL2ROW, ROW2COL*/
#define DIODE_DIRECTION COL2ROW

/* RGB array */
#define RGB_DI_PIN F1
#define RGBLED_NUM 30
#define RGBLIGHT_HUE_STEP 8         // HSV steps for animations
#define RGBLIGHT_SAT_STEP 8
#define RGBLIGHT_VAL_STEP 8
#define RGBLIGHT_LIMIT_VAL 128      // Half brightness to save power
#define RGBLIGHT_DEFAULT_MODE RGBLIGHT_MODE_STATIC_LIGHT
#define RGBLIGHT_ANIMATIONS         // For more options see: https://beta.docs.qmk.fm/using-qmk/hardware-features/lighting/feature_rgblight

/* OLED Display */

#define OLED_DISPLAY_ADDRESS 0x78
#define OLED_IC OLED_IC_SSD1306
#define OLED_DISPLAY_128X64 true

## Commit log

2021-08-13 Bulk of the schematic done
    [LEDs.sch, Macropad.kicad_pcb, Macropad.sch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]
2021-08-14 Schematic mostly done. Started grouping components in layout
    [LEDs.sch, Macropad.kicad_pcb, Macropad.sch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]
2021-08-15 First pass of the layout done
    [LEDs.sch, Macropad.kicad_pcb, Macropad.sch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]
2021-08-18 Redoing layout with key switches upside down for better LED placement
    [Macropad.kicad_pcb, Macropad_route_v0.kicad_pcb, Switches.sch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]
2021-08-19 Layout done, cleaned up schematic and generated gerbers
    [LEDs.sch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]
2021-08-19 removing redundant layout files
    [Macropad_placement_v0.kicad_pcb, Macropad_route_v0.kicad_pcb]
2021-09-11 Updating 3D models, mapping models for USB and encoder
    [Macropad.kicad_pcb, Macropad.sch, USB.sch]
2021-09-11 Adding schematic pdf
2021-09-12 Adding board DXFs
    [Macropad-B_CrtYd.dxf, Macropad-Dwgs_User.dxf, Macropad-F_CrtYd.dxf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]
2021-09-12 Adding frame file and board 3D model
    [back_frame.STL, bottom_space_frame.STL, key_frame.STL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]
2021-09-12 Fixing a naming mistake in schematic
    [LEDs.sch, Macropad.kicad_pcb]
2021-09-12 Adding BOM
    [Macropad_BOM.csv]
2021-09-14 Adding part description field to BOM
    [Macropad_BOM.csv]
2021-10-30 Adding supporting members
    [bottom_space_frame.STL]
2021-10-30 Including DFU reset button in mechanical assembly
    [Macropad.kicad_pcb, back_frame.STL]
2022-05-12 Updating for 3D printing and to fix clashes
    [back_frame.STL, bottom_space_frame.STL, key_frame.STL]
2022-05-12 Moving hardware files to v1 directory
    [LEDs.sch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]
2022-05-12 Adding hardware v2 project
    [LEDs.sch, Macropad.kicad_pcb, Macropad.sch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]
2022-05-18 Updating hardware version numbers
    [LEDs.sch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]
2022-05-18 Removing v2
    [LEDs.sch, Macropad.kicad_pcb, Macropad.sch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]
2022-05-18 Removing gerbers
    [Macropad-B_Cu.gbr, Macropad-B_Mask.gbr, Macropad-B_Paste.gbr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]
2022-05-18 Adding USB termination, moving I2C lines to TWI pins
    [USB.sch, USB_HUB.sch, uController.sch]
2022-05-19 Moving underglow LED and USB VBUS decoupling caps
    [Macropad.kicad_pcb, USB.sch, USB_HUB.sch]
2022-05-19 Connected USB resistors
    [Macropad.kicad_pcb]
2022-05-21 Disconecting mounting holes from ground Adding schmitt trigger bugger to USB HUB reset Cleaning up routing and fixing plane connections
    [Macropad.kicad_pcb, Switches.sch, USB_HUB.sch]
2022-05-21 Fixing silk clashes
    [Macropad.kicad_pcb]
2022-05-21 Adding LED power draw spreadsheet
    [power_calculations.ods]
2022-08-07 v1 gerbers
    [Macropad-B_Cu.gbr, Macropad-B_Mask.gbr, Macropad-B_Paste.gbr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]
2022-08-08 Generating v1 schematic
